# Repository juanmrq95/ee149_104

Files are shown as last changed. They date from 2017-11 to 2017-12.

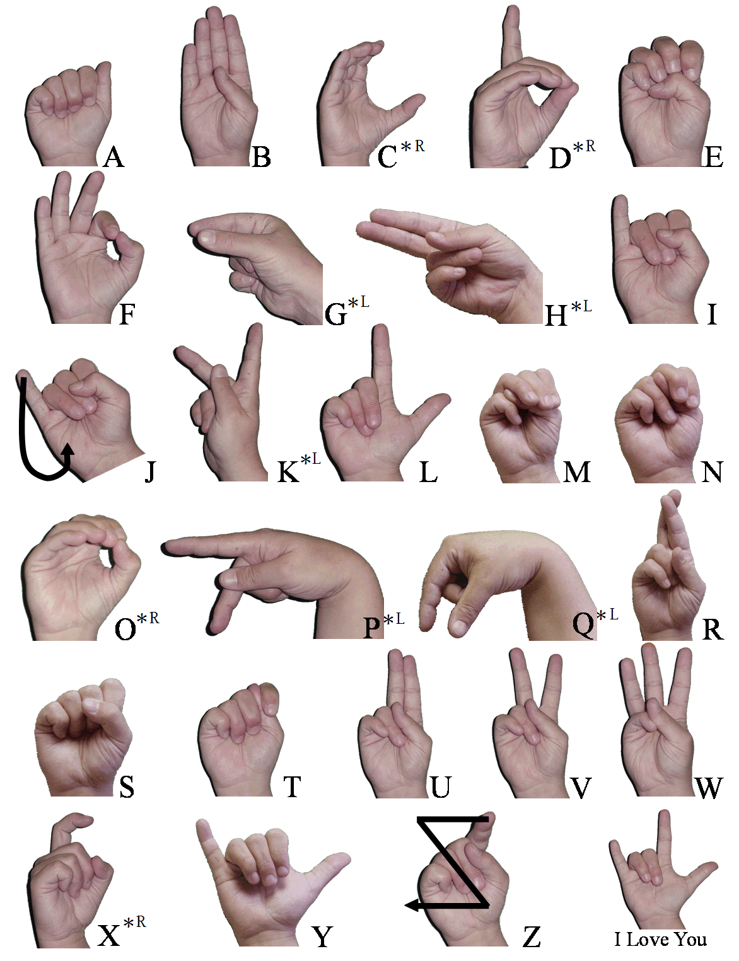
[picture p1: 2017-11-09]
ASLsensing/Pasted image at 2017_10_18 04_46 PM.png

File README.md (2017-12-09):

# ee149_104
EE149 project

ASL Glove:

We created a glove able to interpret every gesture in the ASL alphabet and translate it to text and speech.
We did so by putting touch and flex sensors as well as an IMU embedded on the glove. We designed a sensing circuit 
embedded on the backside of the glove on a flexible PCB sheet as well a small PCB for interfacing with our microprocessor
placed on the wrist.

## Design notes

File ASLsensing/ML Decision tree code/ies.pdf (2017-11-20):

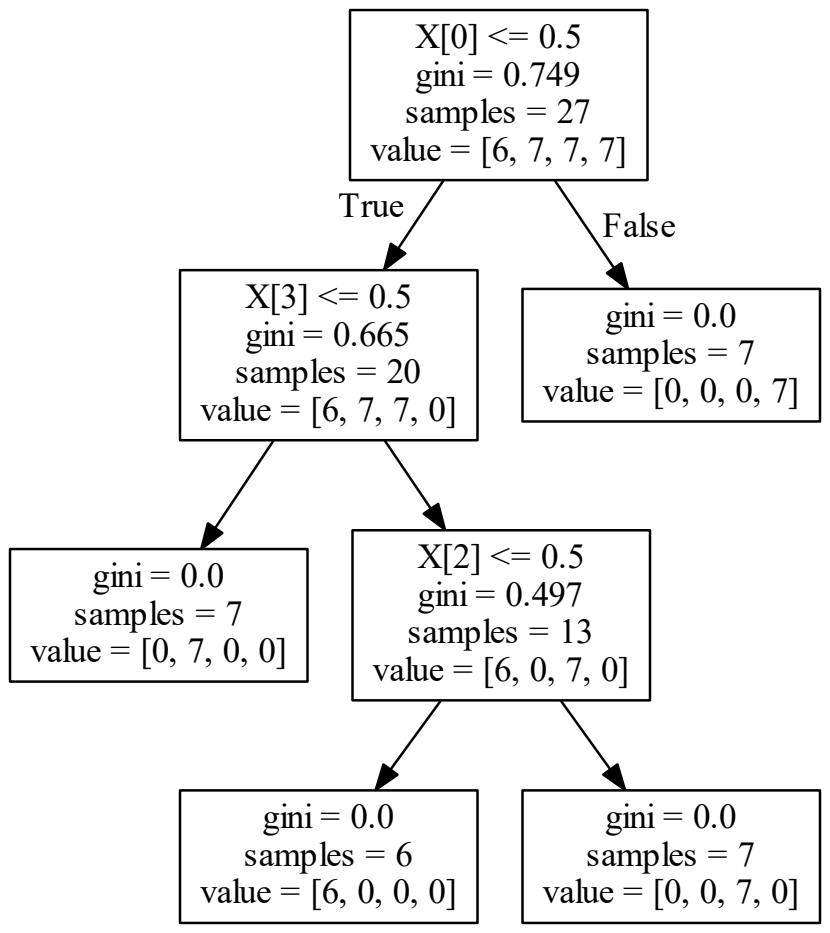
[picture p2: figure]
X[0] <= 0.5 gini = 0.749 samples = 27 value = [6, 7, 7, 7]; X[3] <= 0.5 gini = 0.665 samples = 20 value = [6, 7, 7, 0]; True; gini = 0.0 samples = 7 value = [0, 0, 0, 7]; False; gini = 0.0 samples = 7 value = [0, 7, 0, 0]; X[2] <= 0.5 gini = 0.497 samples = 13 value = [6, 0, 7, 0]; gini = 0.0 samples = 6 value = [6, 0, 0, 0]; gini = 0.0 samples = 7 value = [0, 0, 7, 0]

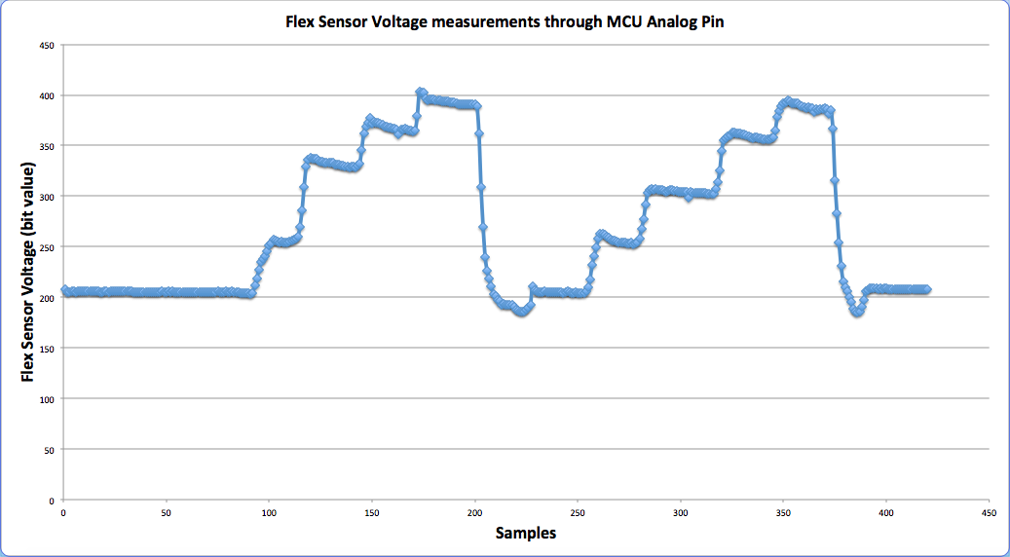
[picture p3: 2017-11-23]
random/flexVoltage.png

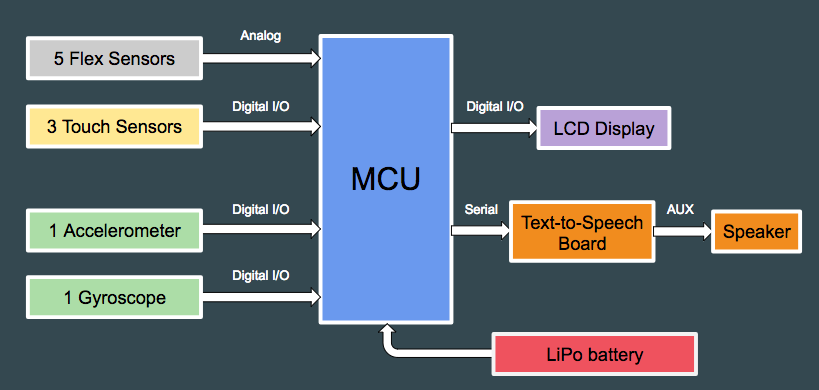
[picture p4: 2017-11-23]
random/Screen Shot 2017-11-21 at 3.47.04 PM.png

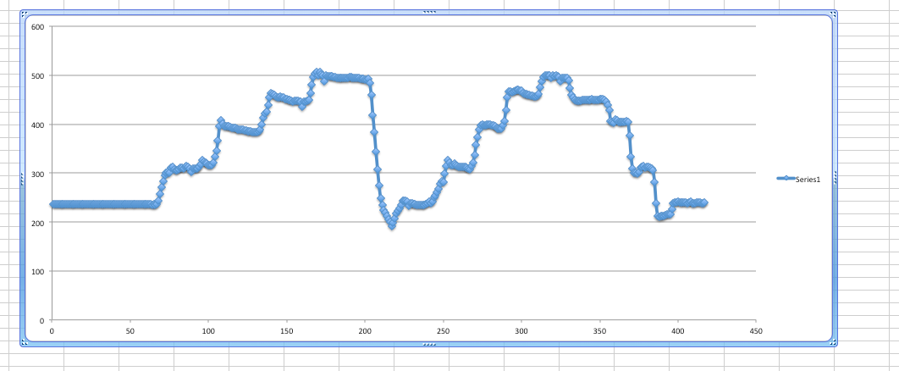
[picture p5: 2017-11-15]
random/Screen Shot 2017-11-13 at 3.06.54 PM.png

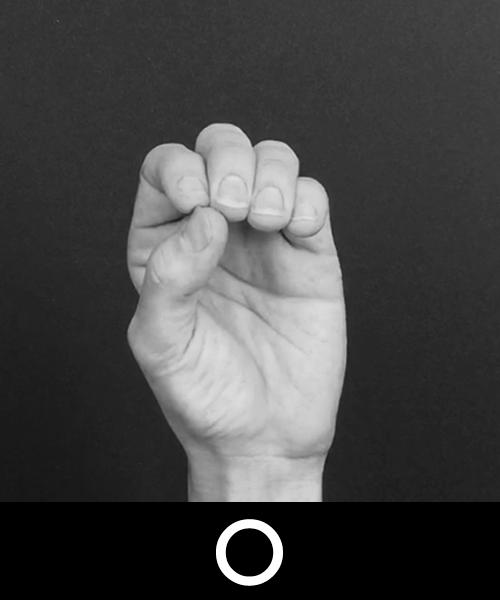
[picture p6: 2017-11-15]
random/O-T.gif

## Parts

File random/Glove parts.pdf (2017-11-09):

Parts to order:

- Silk glove:
https://www.amazon.com/ALASKA-BEAR-Natural-Gloves-Thermal/dp/B00PIMIZWA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 (https://www.amazon.com/ALASKA-BEAR-Natural-Gloves-Thermal/dp/B00PIMIZWA?s=aps)
- Cool glove:
https://www.amazon.com/Terramar-W7467-Body-Sensors-Glove-Liner/dp/B002NPBU36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 (https://www.amazon.com/Terramar-W7467-Body-Sensors-Glove-Liner/dp/B002NPBU36)
- 2 Short flex sensor: https://www.adafruit.com/product/1070
- 3 Long flex sensor: https://www.adafruit.com/product/182
- Microcontroller: FRDM-K64F: https://os.mbed.com/platforms/FRDM-K64F/
- Conductive fabric: https://www.adafruit.com/product/1168

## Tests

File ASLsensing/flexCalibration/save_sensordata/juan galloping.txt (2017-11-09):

500
500
504
508
512
495
495
495
495
495
494
494
493
492
493
494
497
500
504
508
508
501
464
445
438
437
442
451
461
472
483
492
501
508
514
518
521
522
524
525
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

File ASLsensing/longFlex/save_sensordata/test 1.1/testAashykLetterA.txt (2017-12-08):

1r_side 0   m_tip: 0   m_b: 0   m_side: 0   i_tip: 0   i_side: 0   p_side: 0thumb: 6   index: 1   middle: 2   ring: 1   pinky: 2 X: 0.13  Y: 359.35  Z: 0.39
r_side 0   m_tip: 0   m_b: 0   m_side: 0   i_tip: 0   i_side: 0   p_side: 0thumb: 6   index: 1   middle: 2   ring: 1   pinky: 1 X: 0.13  Y: 1.44  Z: 357.90
r_side 0   m_tip: 0   m_b: 0   m_side: 0   i_tip: 0   i_side: 0   p_side: 0thumb: 8   index: 1   middle: 2   ring: 1   pinky: 1 X: 359.97  Y: 3.42  Z: 355.70
r_side 0   m_tip: 0   m_b: 0   m_side: 0   i_tip: 0   i_side: 0   p_side: 0thumb: 6   index: 1   middle: 2   ring: 1   pinky: 1 X: 359.80  Y: 5.33  Z: 353.47
r_side 0   m_tip: 0   m_b: 0   m_side: 0   i_tip: 0   i_side: 0   p_side: 0thumb: 6   index: 0   middle: 2   ring: 1   pinky: 1 X: 359.55  Y: 6.97  Z: 351.30
r_side 0   m_tip: 0   m_b: 0   m_side: 0   i_tip: 0   i_side: 0   p_side: 0thumb: 7   index: 1   middle: 2   ring: 1   pinky: 1 X: 359.28  Y: 8.51  Z: 349.23
r_side 0   m_tip: 0   m_b: 0   m_side: 0   i_tip: 0   i_side: 0   p_side: 0thumb: 8   index: 0   middle: 2   ring: 1   pinky: 1 X: 358.87  Y: 10.12  Z: 347.26
r_side 0   m_tip: 0   m_b: 0   m_side: 0   i_tip: 0   i_side: 0   p_side: 0thumb: 6   index: 1   middle: 2   ring: 1   pinky: 1 X: 358.68  Y: 10.55  Z: 345.72
r_side 0   m_tip: 0   m_b: 0   m_side: 0   i_tip: 0   i_side: 0   p_side: 0thumb: 6   index: 1   middle: 3   ring: 2   pinky: 1 X: 358.55  Y: 11.56  Z: 344.18
r_side 0   m_tip: 0   m_b: 0   m_side: 0   i_tip: 0   i_side: 0   p_side: 0thumb: 6   index: 1   middle: 2   ring: 2   pinky: 1 X: 358.24  Y: 11.93  Z: 342.69
r_side 0   m_tip: 0   m_b: 0   m_side: 0   i_tip: 0   i_side: 0   p_side: 0thumb: 7   index: 1   middle: 2   ring: 1   pinky: 2 X: 356.96  Y: 15.00  Z: 340.89
r_side 0   m_tip: 0   m_b: 0   m_side: 0   i_tip: 0   i_side: 0   p_side: 0thumb: 6   index: 1   middle: 2   ring: 2   pinky: 1 X: 354.32  Y: 22.76  Z: 341.18
r_side 0   m_tip: 0   m_b: 0   m_side: 0   i_tip: 0   i_side: 0   p_side: 0thumb: 6   index: 1   middle: 2   ring: 2   pinky: 1 X: 349.62  Y: 34.87  Z: 338.56
r_side 0   m_tip: 0   m_b: 0   m_side: 0   i_tip: 0   i_side: 0   p_side: 0thumb: 6   index: 2   middle: 3   ring: 3   pinky: 2 X: 332.29  Y: 53.36  Z: 323.33
r_side 0   m_tip: 0   m_b: 0   m_side: 0   i_tip: 0   i_side: 0   p_side: 0thumb: 7   index: 6   middle: 6   ring: 11   pinky: 5 X: 311.81  Y: 60.47  Z: 302.97
r_side 0   m_tip: 0   m_b: 0   m_side: 0   i_tip: 0   i_side: 0   p_side: 0thumb: 10   index: 17   middle: 16   ring: 18   pinky: 15 X: 301.64  Y: 61.44  Z: 292.10
r_side 0   m_tip: 0   m_b: 0   m_side: 0   i_tip: 0   i_side: 0   p_side: 0thumb: 10   index: 21   middle: 20   ring: 21   pinky: 19 X: 292.48  Y: 61.81  Z: 284.01
r_side 0   m_tip: 0   m_b: 0   m_side: 0   i_tip: 0   i_side: 1   p_side: 0thumb: 8   index: 22   middle: 21   ring: 22   pinky: 21 X: 284.69  Y: 67.08  Z: 276.11
r_side 0   m_tip: 0   m_b: 0   m_side: 0   i_tip: 0   i_side: 1   p_side: 0thumb: 8   index: 22   middle: 20   ring: 22   pinky: 21 X: 279.93  Y: 67.51  Z: 271.44
r_side 0   m_tip: 0   m_b: 0   m_side: 0   i_tip: 0   i_side: 1   p_side: 0thumb: 7   index: 21   middle: 20   ring: 21   pinky: 21 X: 278.90  Y: 68.42  Z: 270.73
r_side 0   m_tip: 0   m_b: 0   m_side: 0   i_tip: 0   i_side: 1   p_side: 0thumb: 7   index: 21   middle: 20   ring: 21   pinky: 20 X: 278.82  Y: 67.95  Z: 271.17
r_side 0   m_tip: 0   m_b: 0   m_side: 0   i_tip: 0   i_side: 1   p_side: 0thumb: 7   index: 21   middle: 19   ring: 21   pinky: 20 X: 278.01  Y: 68.12  Z: 270.42
r_side 0   m_tip: 0   m_b: 0   m_side: 0   i_tip: 0   i_side: 1   p_side: 0thumb: 6   index: 21   middle: 19   ring: 21   pinky: 20 X: 276.91  Y: 67.68  Z: 269.46
r_side 0   m_tip: 0   m_b: 0   m_side: 0   i_tip: 0   i_side: 1   p_side: 0thumb: 7   index: 21   middle: 19   ring: 21   pinky: 20 X: 277.85  Y: 66.81  Z: 270.92
r_side 0   m_tip: 0   m_b: 0   m_side: 0   i_tip: 0   i_side: 1   p_side: 0thumb: 7   index: 21   middle: 19   ring: 20   pinky: 20 X: 278.73  Y: 66.07  Z: 271.89
r_side 0   m_tip: 0   m_b: 0   m_side: 0   i_tip: 0   i_side: 1   p_side: 0thumb: 7   index: 21   middle: 19   ring: 20   pinky: 20 X: 278.77  Y: 64.64  Z: 272.66
r_side 0   m_tip: 0   m_b: 0   m_side: 0   i_tip: 0   i_side: 1   p_side: 0thumb: 7   index: 21   middle: 19   ring: 20   pinky: 20 X: 279.12  Y: 64.10  Z: 272.98
r_side 0   m_tip: 0   m_b: 0   m_side: 0   i_tip: 0   i_side: 1   p_side: 0thumb: 7   index: 21   middle: 19   ring: 20   pinky: 20 X: 278.77  Y: 63.57  Z: 272.75
r_side 0   m_tip: 0   m_b: 0   m_side: 0   i_tip: 0   i_side: 1   p_side: 0thumb: 6   index: 20   middle: 19   ring: 20   pinky: 19 X: 277.86  Y: 62.98  Z: 271.75
r_side 0   m_tip: 1   m_b: 0   m_side: 0   i_tip: 0   i_side: 1   p_side: 0thumb: 7   index: 20   middle: 19   ring: 21   pinky: 19 X: 277.18  Y: 62.36  Z: 271.08
r_side 0   m_tip: 1   m_b: 0   m_side: 0   i_tip: 0   i_side: 1   p_side: 0thumb: 7   index: 20   middle: 18   ring: 20   pinky: 19 X: 278.20  Y: 61.51  Z: 271.98
r_side 0   m_tip: 1   m_b: 0   m_side: 0   i_tip: 0   i_side: 1   p_side: 0thumb: 7   index: 20   middle: 19   ring: 20   pinky: 19 X: 277.54  Y: 60.52  Z: 271.65
r_side 0   m_tip: 1   m_b: 0   m_side: 0   i_tip: 0   i_side: 1   p_side: 0thumb: 7   index: 20   middle: 19   ring: 20   pinky: 19 X: 277.64  Y: 59.69  Z: 271.74
r_side 0   m_tip: 1   m_b: 0   m_side: 0   i_tip: 0   i_side: 1   p_side: 0thumb: 6   index: 20   middle: 19   ring: 20   pinky: 19 X: 277.37  Y: 59.08  Z: 271.55
r_side 0   m_tip: 1   m_b: 0   m_side: 0   i_tip: 0   i_side: 1   p_side: 0thumb: 6   index: 20   middle: 18   ring: 19   pinky: 19 X: 279.48  Y: 59.81  Z: 273.34
r_side 0   m_tip: 1   m_b: 0   m_side: 0   i_tip: 0   i_side: 1   p_side: 0thumb: 6   index: 20   middle: 18   ring: 20   pinky: 19 X: 280.43  Y: 59.54  Z: 274.35
r_side 0   m_tip: 1   m_b: 0   m_side: 0   i_tip: 0   i_side: 1   p_side: 0thumb: 7   index: 20   middle: 18   ring: 19   pinky: 19 X: 279.67  Y: 59.21  Z: 273.93
r_side 0   m_tip: 1   m_b: 0   m_side: 0   i_tip: 0   i_side: 1   p_side: 0thumb: 6   index: 20   middle: 18   ring: 19   pinky: 19 X: 280.38  Y: 58.26  Z: 274.65
r_side 0   m_tip: 1   m_b: 0   m_side: 0   i_tip: 0   i_side: 1   p_side: 0thumb: 6   index: 20   middle: 18   ring: 19   pinky: 19 X: 280.50  Y: 57.42  Z: 274.91
r_side 0   m_tip: 1   m_b: 0   m_side: 0   i_tip: 0   i_side: 1   p_side: 0thumb: 6   index: 20   middle: 18   ring: 19   pinky: 19 X: 281.61  Y: 56.66  Z: 275.97

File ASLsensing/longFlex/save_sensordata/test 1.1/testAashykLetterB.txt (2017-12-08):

_r_side 0   m_tip: 0   m_b: 0   m_side: 0   i_tip: 0   i_side: 0   p_side: 0thumb: 4   index: 0   middle: 2   ring: 2   pinky: 2 X: 359.47  Y: 0.78  Z: 359.21
r_side 0   m_tip: 0   m_b: 0   m_side: 0   i_tip: 0   i_side: 0   p_side: 0thumb: 4   index: 0   middle: 2   ring: 2   pinky: 2 X: 359.39  Y: 1.75  Z: 356.61
r_side 0   m_tip: 0   m_b: 0   m_side: 0   i_tip: 0   i_side: 0   p_side: 0thumb: 4   index: 0   middle: 2   ring: 2   pinky: 2 X: 359.32  Y: 2.48  Z: 354.28
r_side 0   m_tip: 0   m_b: 0   m_side: 0   i_tip: 0   i_side: 0   p_side: 0thumb: 4   index: 0   middle: 2   ring: 1   pinky: 2 X: 359.28  Y: 3.41  Z: 351.93
r_side 0   m_tip: 0   m_b: 0   m_side: 0   i_tip: 0   i_side: 0   p_side: 0thumb: 4   index: 0   middle: 2   ring: 2   pinky: 2 X: 359.11  Y: 4.34  Z: 349.74
r_side 0   m_tip: 0   m_b: 0   m_side: 0   i_tip: 0   i_side: 0   p_side: 0thumb: 4   index: 0   middle: 2   ring: 2   pinky: 2 X: 359.00  Y: 5.09  Z: 347.81
r_side 0   m_tip: 0   m_b: 0   m_side: 0   i_tip: 0   i_side: 0   p_side: 0thumb: 4   index: 0   middle: 2   ring: 2   pinky: 2 X: 358.94  Y: 5.48  Z: 346.03
r_side 0   m_tip: 0   m_b: 0   m_side: 0   i_tip: 0   i_side: 0   p_side: 0thumb: 4   index: 0   middle: 2   ring: 2   pinky: 2 X: 359.07  Y: 5.82  Z: 344.29
r_side 0   m_tip: 0   m_b: 0   m_side: 0   i_tip: 0   i_side: 0   p_side: 0thumb: 4   index: 1   middle: 2   ring: 2   pinky: 2 X: 358.94  Y: 5.91  Z: 341.17
r_side 0   m_tip: 0   m_b: 0   m_side: 0   i_tip: 0   i_side: 0   p_side: 0thumb: 4   index: 1   middle: 2   ring: 2   pinky: 2 X: 354.75  Y: 13.08  Z: 339.47
r_side 0   m_tip: 0   m_b: 0   m_side: 0   i_tip: 0   i_side: 0   p_side: 0thumb: 4   index: 1   middle: 2   ring: 3   pinky: 2 X: 347.16  Y: 31.93  Z: 336.28
r_side 0   m_tip: 0   m_b: 0   m_side: 0   i_tip: 0   i_side: 0   p_side: 0thumb: 18   index: 3   middle: 3   ring: 4   pinky: 2 X: 335.03  Y: 46.49  Z: 328.26
r_side 0   m_tip: 0   m_b: 0   m_side: 0   i_tip: 0   i_side: 0   p_side: 0thumb: 20   index: 2   middle: 3   ring: 3   pinky: 2 X: 322.54  Y: 58.75  Z: 322.14
r_side 0   m_tip: 0   m_b: 0   m_side: 0   i_tip: 0   i_side: 0   p_side: 0thumb: 20   index: 1   middle: 3   ring: 2   pinky: 2 X: 314.96  Y: 64.48  Z: 318.64
r_side 0   m_tip: 0   m_b: 0   m_side: 0   i_tip: 0   i_side: 0   p_side: 0thumb: 19   index: 1   middle: 2   ring: 2   pinky: 2 X: 290.35  Y: 68.64  Z: 296.50
r_side 0   m_tip: 0   m_b: 0   m_side: 0   i_tip: 0   i_side: 0   p_side: 0thumb: 19   index: 1   middle: 2   ring: 2   pinky: 2 X: 280.20  Y: 67.24  Z: 288.97
r_side 0   m_tip: 0   m_b: 0   m_side: 0   i_tip: 0   i_side: 0   p_side: 0thumb: 21   index: 2   middle: 2   ring: 2   pinky: 2 X: 278.30  Y: 67.67  Z: 286.71
r_side 0   m_tip: 0   m_b: 0   m_side: 0   i_tip: 0   i_side: 0   p_side: 0thumb: 19   index: 1   middle: 2   ring: 2   pinky: 1 X: 277.95  Y: 66.65  Z: 285.26
r_side 0   m_tip: 0   m_b: 0   m_side: 0   i_tip: 0   i_side: 0   p_side: 0thumb: 19   index: 1   middle: 2   ring: 1   pinky: 1 X: 279.14  Y: 65.26  Z: 284.90
r_side 0   m_tip: 0   m_b: 0   m_side: 0   i_tip: 0   i_side: 0   p_side: 0thumb: 19   index: 1   middle: 2   ring: 1   pinky: 1 X: 281.15  Y: 63.52  Z: 285.59
r_side 0   m_tip: 0   m_b: 0   m_side: 0   i_tip: 0   i_side: 0   p_side: 0thumb: 19   index: 1   middle: 2   ring: 1   pinky: 1 X: 282.74  Y: 62.89  Z: 286.66
r_side 0   m_tip: 0   m_b: 0   m_side: 0   i_tip: 0   i_side: 0   p_side: 0thumb: 18   index: 0   middle: 2   ring: 1   pinky: 1 X: 284.50  Y: 61.96  Z: 287.46
r_side 0   m_tip: 0   m_b: 0   m_side: 0   i_tip: 0   i_side: 0   p_side: 0thumb: 19   index: 1   middle: 2   ring: 1   pinky: 1 X: 287.51  Y: 62.13  Z: 290.24
r_side 0   m_tip: 0   m_b: 0   m_side: 0   i_tip: 0   i_side: 0   p_side: 0thumb: 18   index: 1   middle: 2   ring: 1   pinky: 1 X: 287.23  Y: 62.04  Z: 289.72
r_side 0   m_tip: 0   m_b: 0   m_side: 0   i_tip: 0   i_side: 0   p_side: 0thumb: 18   index: 1   middle: 2   ring: 1   pinky: 1 X: 288.37  Y: 60.62  Z: 291.27
r_side 0   m_tip: 0   m_b: 0   m_side: 0   i_tip: 0   i_side: 0   p_side: 0thumb: 18   index: 1   middle: 2   ring: 1   pinky: 1 X: 290.02  Y: 59.96  Z: 292.60
r_side 0   m_tip: 0   m_b: 0   m_side: 0   i_tip: 0   i_side: 0   p_side: 0thumb: 19   index: 1   middle: 2   ring: 1   pinky: 1 X: 289.76  Y: 59.02  Z: 291.78
r_side 0   m_tip: 0   m_b: 0   m_side: 0   i_tip: 0   i_side: 0   p_side: 0thumb: 18   index: 0   middle: 2   ring: 1   pinky: 1 X: 287.30  Y: 59.18  Z: 289.36
r_side 0   m_tip: 0   m_b: 0   m_side: 0   i_tip: 0   i_side: 0   p_side: 0thumb: 18   index: 0   middle: 2   ring: 1   pinky: 1 X: 286.74  Y: 58.90  Z: 288.61
r_side 0   m_tip: 0   m_b: 0   m_side: 0   i_tip: 0   i_side: 0   p_side: 0thumb: 18   index: 1   middle: 2   ring: 1   pinky: 1 X: 288.34  Y: 57.88  Z: 289.62
r_side 0   m_tip: 0   m_b: 0   m_side: 0   i_tip: 0   i_side: 0   p_side: 0thumb: 18   index: 0   middle: 2   ring: 1   pinky: 1 X: 290.48  Y: 56.76  Z: 291.15
r_side 0   m_tip: 0   m_b: 0   m_side: 0   i_tip: 0   i_side: 0   p_side: 0thumb: 18   index: 1   middle: 2   ring: 1   pinky: 1 X: 291.22  Y: 55.86  Z: 291.68
r_side 0   m_tip: 0   m_b: 0   m_side: 0   i_tip: 0   i_side: 0   p_side: 0thumb: 18   index: 0   middle: 2   ring: 1   pinky: 1 X: 291.06  Y: 55.42  Z: 291.99
r_side 0   m_tip: 0   m_b: 0   m_side: 0   i_tip: 0   i_side: 0   p_side: 0thumb: 19   index: 1   middle: 2   ring: 1   pinky: 1 X: 290.25  Y: 54.37  Z: 291.12
r_side 0   m_tip: 0   m_b: 0   m_side: 0   i_tip: 0   i_side: 0   p_side: 0thumb: 18   index: 1   middle: 2   ring: 1   pinky: 1 X: 290.88  Y: 53.06  Z: 290.71
r_side 0   m_tip: 0   m_b: 0   m_side: 0   i_tip: 0   i_side: 0   p_side: 0thumb: 18   index: 1   middle: 2   ring: 1   pinky: 1 X: 291.80  Y: 51.16  Z: 291.29
r_side 0   m_tip: 0   m_b: 0   m_side: 0   i_tip: 0   i_side: 0   p_side: 0thumb: 18   index: 0   middle: 2   ring: 1   pinky: 1 X: 290.36  Y: 50.74  Z: 289.70
r_side 0   m_tip: 0   m_b: 0   m_side: 0   i_tip: 0   i_side: 0   p_side: 0thumb: 18   index: 1   middle: 2   ring: 1   pinky: 1 X: 289.79  Y: 50.04  Z: 289.32
r_side 0   m_tip: 0   m_b: 0   m_side: 0   i_tip: 0   i_side: 0   p_side: 0thumb: 18   index: 1   middle: 2   ring: 1   pinky: 1 X: 289.44  Y: 49.50  Z: 289.20
r_side 0   m_tip: 0   m_b: 0   m_side: 0   i_tip: 0   i_side: 0   p_side: 0thumb: 18   index: 0   middle: 2   ring: 1   pinky: 1 X: 289.24  Y: 48.61  Z: 289.26

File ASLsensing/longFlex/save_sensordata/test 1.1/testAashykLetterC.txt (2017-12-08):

ðr_side 0   m_tip: 0   m_b: 0   m_side: 0   i_tip: 0   i_side: 0   p_side: 0thumb: 5   index: 0   middle: 2   ring: 1   pinky: 1 X: 359.48  Y: 1.69  Z: 0.39
r_side 0   m_tip: 0   m_b: 0   m_side: 0   i_tip: 0   i_side: 0   p_side: 0thumb: 5   index: 0   middle: 2   ring: 1   pinky: 1 X: 359.42  Y: 2.41  Z: 357.90
r_side 0   m_tip: 0   m_b: 0   m_side: 0   i_tip: 0   i_side: 0   p_side: 0thumb: 5   index: 0   middle: 2   ring: 1   pinky: 1 X: 359.37  Y: 3.25  Z: 355.46
r_side 0   m_tip: 0   m_b: 0   m_side: 0   i_tip: 0   i_side: 0   p_side: 0thumb: 5   index: 0   middle: 2   ring: 1   pinky: 1 X: 359.37  Y: 3.72  Z: 353.05
r_side 0   m_tip: 0   m_b: 0   m_side: 0   i_tip: 0   i_side: 0   p_side: 0thumb: 6   index: 0   middle: 2   ring: 2   pinky: 1 X: 359.29  Y: 4.42  Z: 350.93
r_side 0   m_tip: 0   m_b: 0   m_side: 0   i_tip: 0   i_side: 0   p_side: 0thumb: 6   index: 0   middle: 2   ring: 1   pinky: 1 X: 359.13  Y: 5.17  Z: 348.94
r_side 0   m_tip: 0   m_b: 0   m_side: 0   i_tip: 0   i_side: 0   p_side: 0thumb: 5   index: 0   middle: 2   ring: 1   pinky: 1 X: 358.98  Y: 6.08  Z: 347.13
r_side 0   m_tip: 0   m_b: 0   m_side: 0   i_tip: 0   i_side: 0   p_side: 0thumb: 5   index: 0   middle: 2   ring: 1   pinky: 1 X: 358.81  Y: 6.49  Z: 345.77
r_side 0   m_tip: 0   m_b: 0   m_side: 0   i_tip: 0   i_side: 0   p_side: 0thumb: 4   index: 0   middle: 1   ring: 0   pinky: 2 X: 358.49  Y: 7.22  Z: 344.10
r_side 0   m_tip: 0   m_b: 0   m_side: 0   i_tip: 0   i_side: 0   p_side: 0thumb: 6   index: 0   middle: 2   ring: 1   pinky: 1 X: 358.30  Y: 7.83  Z: 342.69
r_side 0   m_tip: 0   m_b: 0   m_side: 0   i_tip: 0   i_side: 0   p_side: 0thumb: 5   index: 0   middle: 2   ring: 1   pinky: 1 X: 358.03  Y: 8.46  Z: 341.42
r_side 0   m_tip: 0   m_b: 0   m_side: 0   i_tip: 0   i_side: 0   p_side: 0thumb: 5   index: 0   middle: 2   ring: 1   pinky: 1 X: 357.77  Y: 9.36  Z: 340.25
r_side 0   m_tip: 0   m_b: 0   m_side: 0   i_tip: 0   i_side: 0   p_side: 0thumb: 5   index: 0   middle: 1   ring: 1   pinky: 1 X: 357.70  Y: 9.69  Z: 339.22
r_side 0   m_tip: 0   m_b: 0   m_side: 0   i_tip: 0   i_side: 0   p_side: 0thumb: 5   index: 0   middle: 2   ring: 1   pinky: 1 X: 357.48  Y: 10.12  Z: 338.18
r_side 0   m_tip: 0   m_b: 0   m_side: 0   i_tip: 0   i_side: 0   p_side: 0thumb: 5   index: 0   middle: 2   ring: 1   pinky: 1 X: 357.29  Y: 10.28  Z: 337.45
r_side 0   m_tip: 0   m_b: 0   m_side: 0   i_tip: 0   i_side: 0   p_side: 0thumb: 5   index: 0   middle: 2   ring: 1   pinky: 1 X: 357.15  Y: 10.86  Z: 336.66
r_side 0   m_tip: 0   m_b: 0   m_side: 0   i_tip: 0   i_side: 0   p_side: 0thumb: 6   index: 0   middle: 1   ring: 1   pinky: 1 X: 357.17  Y: 10.68  Z: 336.23
r_side 0   m_tip: 0   m_b: 0   m_side: 0   i_tip: 0   i_side: 0   p_side: 0thumb: 5   index: 0   middle: 1   ring: 1   pinky: 1 X: 357.23  Y: 7.20  Z: 334.22
r_side 0   m_tip: 0   m_b: 0   m_side: 0   i_tip: 0   i_side: 0   p_side: 0thumb: 5   index: 0   middle: 2   ring: 1   pinky: 1 X: 354.87  Y: 9.94  Z: 334.68
r_side 0   m_tip: 0   m_b: 0   m_side: 0   i_tip: 0   i_side: 0   p_side: 0thumb: 5   index: 0   middle: 2   ring: 2   pinky: 1 X: 352.17  Y: 16.57  Z: 335.18
r_side 0   m_tip: 0   m_b: 0   m_side: 0   i_tip: 0   i_side: 0   p_side: 0thumb: 5   index: 5   middle: 7   ring: 11   pinky: 2 X: 350.46  Y: 29.31  Z: 335.54
r_side 0   m_tip: 0   m_b: 0   m_side: 0   i_tip: 0   i_side: 0   p_side: 0thumb: 9   index: 15   middle: 15   ring: 17   pinky: 9 X: 346.51  Y: 37.80  Z: 333.40
r_side 0   m_tip: 0   m_b: 0   m_side: 0   i_tip: 0   i_side: 0   p_side: 0thumb: 12   index: 18   middle: 16   ring: 18   pinky: 11 X: 345.68  Y: 41.16  Z: 333.90
r_side 0   m_tip: 0   m_b: 0   m_side: 0   i_tip: 0   i_side: 0   p_side: 0thumb: 13   index: 17   middle: 17   ring: 18   pinky: 12 X: 344.35  Y: 44.59  Z: 334.27
r_side 0   m_tip: 0   m_b: 0   m_side: 0   i_tip: 0   i_side: 0   p_side: 0thumb: 14   index: 17   middle: 16   ring: 18   pinky: 12 X: 343.15  Y: 46.07  Z: 333.75
r_side 0   m_tip: 0   m_b: 0   m_side: 0   i_tip: 0   i_side: 0   p_side: 0thumb: 14   index: 16   middle: 16   ring: 17   pinky: 12 X: 341.54  Y: 46.74  Z: 332.30
r_side 0   m_tip: 0   m_b: 0   m_side: 0   i_tip: 0   i_side: 0   p_side: 0thumb: 13   index: 17   middle: 16   ring: 17   pinky: 11 X: 340.19  Y: 47.38  Z: 331.13
r_side 0   m_tip: 0   m_b: 0   m_side: 0   i_tip: 0   i_side: 0   p_side: 0thumb: 13   index: 16   middle: 16   ring: 17   pinky: 11 X: 338.60  Y: 47.11  Z: 329.30
r_side 0   m_tip: 0   m_b: 0   m_side: 0   i_tip: 0   i_side: 0   p_side: 0thumb: 13   index: 16   middle: 16   ring: 17   pinky: 11 X: 337.13  Y: 46.07  Z: 328.01
r_side 0   m_tip: 0   m_b: 0   m_side: 0   i_tip: 0   i_side: 0   p_side: 0thumb: 13   index: 16   middle: 16   ring: 17   pinky: 11 X: 336.40  Y: 46.31  Z: 327.71
r_side 0   m_tip: 0   m_b: 0   m_side: 0   i_tip: 0   i_side: 0   p_side: 0thumb: 13   index: 17   middle: 16   ring: 16   pinky: 11 X: 334.47  Y: 44.88  Z: 325.49
r_side 0   m_tip: 0   m_b: 0   m_side: 0   i_tip: 0   i_side: 0   p_side: 0thumb: 13   index: 16   middle: 16   ring: 16   pinky: 11 X: 333.81  Y: 44.53  Z: 324.79
r_side 0   m_tip: 0   m_b: 0   m_side: 0   i_tip: 0   i_side: 0   p_side: 0thumb: 13   index: 17   middle: 16   ring: 16   pinky: 11 X: 333.64  Y: 44.84  Z: 324.91
r_side 0   m_tip: 0   m_b: 0   m_side: 0   i_tip: 0   i_side: 0   p_side: 0thumb: 13   index: 16   middle: 16   ring: 16   pinky: 11 X: 333.69  Y: 44.14  Z: 325.15
r_side 0   m_tip: 0   m_b: 0   m_side: 0   i_tip: 0   i_side: 0   p_side: 0thumb: 12   index: 16   middle: 15   ring: 16   pinky: 9 X: 333.30  Y: 43.69  Z: 324.85
r_side 0   m_tip: 0   m_b: 0   m_side: 0   i_tip: 0   i_side: 0   p_side: 0thumb: 13   index: 16   middle: 15   ring: 16   pinky: 10 X: 332.50  Y: 43.50  Z: 324.61
r_side 0   m_tip: 0   m_b: 0   m_side: 0   i_tip: 0   i_side: 0   p_side: 0thumb: 13   index: 15   middle: 16   ring: 17   pinky: 10 X: 332.63  Y: 43.43  Z: 324.93
r_side 0   m_tip: 0   m_b: 0   m_side: 0   i_tip: 0   i_side: 0   p_side: 0thumb: 12   index: 15   middle: 16   ring: 15   pinky: 10 X: 333.31  Y: 42.37  Z: 325.55
r_side 0   m_tip: 0   m_b: 0   m_side: 0   i_tip: 0   i_side: 0   p_side: 0thumb: 12   index: 15   middle: 16   ring: 16   pinky: 10 X: 333.60  Y: 42.37  Z: 326.11
r_side 0   m_tip: 0   m_b: 0   m_side: 0   i_tip: 0   i_side: 0   p_side: 0thumb: 13   index: 16   middle: 15   ring: 16   pinky: 10 X: 333.03  Y: 42.07  Z: 325.81
r_side 0   m_tip: 0   m_b: 0   m_side: 0   i_tip: 0   i_side: 0   p_side: 0thumb: 12   index: 16   middle: 15   ring: 16   pinky: 10 X: 333.32  Y: 41.68  Z: 326.30
r_side 0   m_tip: 0   m_b: 0   m_side: 0   i_tip: 0   i_side: 0   p_side: 0thumb: 12   index: 15   middle: 15   ring: 15   pinky: 10 X: 333.04  Y: 41.06  Z: 326.01
r_side 0   m_tip: 0   m_b: 0   m_side: 0   i_tip: 0   i_side: 0   p_side: 0thumb: 12   index: 16   middle: 15   ring: 15   pinky: 10 X: 332.11  Y: 40.57  Z: 325.58
r_side 0   m_tip: 0   m_b: 0   m_side: 0   i_tip: 0   i_side: 0   p_side: 0thumb: 12   index: 15   middle: 15   ring: 15   pinky: 10 X: 331.71  Y: 40.74  Z: 325.26
r_side 0   m_tip: 0   m_b: 0   m_side: 0   i_tip: 0   i_side: 0   p_side: 0thumb: 12   index: 15   middle: 15   ring: 15   pinky: 10 X: 330.96  Y: 40.36  Z: 324.75
r_side 0   m_tip: 0   m_b: 0   m_side: 0   i_tip: 0   i_side: 0   p_side: 0thumb: 11   index: 16   middle: 15   ring: 15   pinky: 10 X: 331.30  Y: 40.15  Z: 325.09
r_side 0   m_tip: 0   m_b: 0   m_side: 0   i_tip: 0   i_side: 0   p_side: 0thumb: 12   index: 15   middle: 15   ring: 15   pinky: 10 X: 330.54  Y: 40.09  Z: 324.69
r_side 0   m_tip: 0   m_b: 0   m_side: 0   i_tip: 0   i_side: 0   p_side: 0thumb: 12   index: 15   middle: 15   ring: 15   pinky: 10 X: 330.37  Y: 39.12  Z: 324.45
r_side 0   m_tip: 0   m_b: 0   m_side: 0   i_tip: 0   i_side: 0   p_side: 0thumb: 13   index: 16   middle: 15   ring: 15   pinky: 9 X: 330.26  Y: 38.62  Z: 325.25

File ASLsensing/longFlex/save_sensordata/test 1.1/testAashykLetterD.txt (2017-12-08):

ür_side 0   m_tip: 0   m_b: 0   m_side: 0   i_tip: 0   i_side: 0   p_side: 0thumb: 6   index: 1   middle: 2   ring: 2   pinky: 2 X: 358.81  Y: 1.94  Z: 359.32
r_side 0   m_tip: 0   m_b: 0   m_side: 0   i_tip: 0   i_side: 0   p_side: 0thumb: 7   index: 1   middle: 2   ring: 2   pinky: 2 X: 358.74  Y: 3.55  Z: 357.06
r_side 0   m_tip: 0   m_b: 0   m_side: 0   i_tip: 0   i_side: 0   p_side: 0thumb: 6   index: 1   middle: 2   ring: 2   pinky: 2 X: 358.61  Y: 5.17  Z: 354.64
r_side 0   m_tip: 0   m_b: 0   m_side: 0   i_tip: 0   i_side: 0   p_side: 0thumb: 7   index: 1   middle: 2   ring: 2   pinky: 2 X: 358.40  Y: 6.80  Z: 352.57
r_side 0   m_tip: 0   m_b: 0   m_side: 0   i_tip: 0   i_side: 0   p_side: 0thumb: 6   index: 1   middle: 2   ring: 2   pinky: 2 X: 358.17  Y: 8.11  Z: 350.36
r_side 0   m_tip: 0   m_b: 0   m_side: 0   i_tip: 0   i_side: 0   p_side: 0thumb: 7   index: 1   middle: 2   ring: 3   pinky: 1 X: 357.88  Y: 9.39  Z: 348.66
r_side 0   m_tip: 0   m_b: 0   m_side: 0   i_tip: 0   i_side: 0   p_side: 0thumb: 6   index: 1   middle: 2   ring: 2   pinky: 1 X: 357.69  Y: 10.46  Z: 347.10
r_side 0   m_tip: 0   m_b: 0   m_side: 0   i_tip: 0   i_side: 0   p_side: 0thumb: 6   index: 1   middle: 2   ring: 2   pinky: 2 X: 356.56  Y: 12.67  Z: 338.60
r_side 0   m_tip: 0   m_b: 0   m_side: 0   i_tip: 0   i_side: 0   p_side: 0thumb: 7   index: 2   middle: 3   ring: 3   pinky: 1 X: 352.12  Y: 23.47  Z: 338.47
r_side 0   m_tip: 0   m_b: 0   m_side: 0   i_tip: 0   i_side: 0   p_side: 0thumb: 6   index: 2   middle: 11   ring: 13   pinky: 2 X: 341.78  Y: 36.21  Z: 331.49
r_side 0   m_tip: 0   m_b: 0   m_side: 0   i_tip: 0   i_side: 0   p_side: 0thumb: 6   index: 2   middle: 14   ring: 15   pinky: 3 X: 336.55  Y: 40.11  Z: 324.92
r_side 0   m_tip: 0   m_b: 0   m_side: 0   i_tip: 0   i_side: 0   p_side: 0thumb: 7   index: 1   middle: 15   ring: 17   pinky: 6 X: 327.63  Y: 43.92  Z: 316.87
r_side 0   m_tip: 0   m_b: 0   m_side: 0   i_tip: 0   i_side: 0   p_side: 0thumb: 9   index: 1   middle: 16   ring: 17   pinky: 9 X: 322.69  Y: 45.01  Z: 311.96
r_side 0   m_tip: 0   m_b: 0   m_side: 0   i_tip: 0   i_side: 0   p_side: 0thumb: 12   index: 1   middle: 15   ring: 17   pinky: 9 X: 321.60  Y: 44.64  Z: 310.20
r_side 0   m_tip: 1   m_b: 0   m_side: 0   i_tip: 0   i_side: 0   p_side: 0thumb: 12   index: 1   middle: 14   ring: 17   pinky: 8 X: 321.65  Y: 44.09  Z: 309.62
r_side 0   m_tip: 1   m_b: 0   m_side: 0   i_tip: 0   i_side: 0   p_side: 0thumb: 12   index: 1   middle: 15   ring: 18   pinky: 8 X: 322.46  Y: 43.40  Z: 308.68
r_side 0   m_tip: 1   m_b: 0   m_side: 0   i_tip: 0   i_side: 0   p_side: 0thumb: 11   index: 1   middle: 16   ring: 18   pinky: 9 X: 323.11  Y: 43.14  Z: 308.49
r_side 0   m_tip: 1   m_b: 0   m_side: 0   i_tip: 0   i_side: 0   p_side: 0thumb: 11   index: 2   middle: 15   ring: 17   pinky: 9 X: 323.01  Y: 40.29  Z: 307.97
r_side 0   m_tip: 1   m_b: 0   m_side: 0   i_tip: 0   i_side: 0   p_side: 0thumb: 11   index: 1   middle: 15   ring: 17   pinky: 10 X: 321.75  Y: 39.57  Z: 307.04
r_side 0   m_tip: 1   m_b: 0   m_side: 0   i_tip: 0   i_side: 0   p_side: 0thumb: 11   index: 1   middle: 14   ring: 17   pinky: 10 X: 320.71  Y: 39.69  Z: 306.17
r_side 0   m_tip: 1   m_b: 0   m_side: 0   i_tip: 0   i_side: 0   p_side: 0thumb: 11   index: 1   middle: 15   ring: 17   pinky: 10 X: 321.41  Y: 39.38  Z: 306.32
r_side 0   m_tip: 1   m_b: 0   m_side: 0   i_tip: 0   i_side: 0   p_side: 0thumb: 11   index: 1   middle: 14   ring: 17   pinky: 10 X: 321.06  Y: 39.03  Z: 305.29
r_side 0   m_tip: 1   m_b: 0   m_side: 0   i_tip: 0   i_side: 0   p_side: 0thumb: 11   index: 1   middle: 14   ring: 17   pinky: 9 X: 320.53  Y: 39.51  Z: 304.29
r_side 0   m_tip: 1   m_b: 0   m_side: 0   i_tip: 0   i_side: 0   p_side: 0thumb: 11   index: 0   middle: 14   ring: 17   pinky: 9 X: 320.58  Y: 40.26  Z: 303.53
r_side 0   m_tip: 1   m_b: 0   m_side: 0   i_tip: 0   i_side: 0   p_side: 0thumb: 12   index: 1   middle: 14   ring: 17   pinky: 9 X: 319.44  Y: 41.17  Z: 302.79
r_side 0   m_tip: 1   m_b: 0   m_side: 0   i_tip: 0   i_side: 0   p_side: 0thumb: 11   index: 1   middle: 14   ring: 16   pinky: 9 X: 317.33  Y: 43.11  Z: 301.54
r_side 0   m_tip: 1   m_b: 0   m_side: 0   i_tip: 0   i_side: 0   p_side: 0thumb: 11   index: 1   middle: 14   ring: 16   pinky: 9 X: 317.07  Y: 43.85  Z: 301.10
r_side 0   m_tip: 1   m_b: 0   m_side: 0   i_tip: 0   i_side: 0   p_side: 0thumb: 11   index: 0   middle: 14   ring: 16   pinky: 9 X: 316.26  Y: 43.93  Z: 300.39
r_side 0   m_tip: 1   m_b: 0   m_side: 0   i_tip: 0   i_side: 0   p_side: 0thumb: 11   index: 0   middle: 14   ring: 16   pinky: 9 X: 315.65  Y: 44.30  Z: 299.54
r_side 0   m_tip: 1   m_b: 0   m_side: 0   i_tip: 0   i_side: 0   p_side: 0thumb: 11   index: 0   middle: 14   ring: 16   pinky: 9 X: 315.70  Y: 44.57  Z: 299.57
r_side 0   m_tip: 1   m_b: 0   m_side: 0   i_tip: 0   i_side: 0   p_side: 0thumb: 11   index: 1   middle: 14   ring: 16   pinky: 9 X: 316.35  Y: 44.34  Z: 300.63
r_side 0   m_tip: 1   m_b: 0   m_side: 0   i_tip: 0   i_side: 0   p_side: 0thumb: 11   index: 1   middle: 14   ring: 16   pinky: 9 X: 317.33  Y: 43.72  Z: 301.03
r_side 0   m_tip: 1   m_b: 0   m_side: 0   i_tip: 0   i_side: 0   p_side: 0thumb: 11   index: 1   middle: 14   ring: 16   pinky: 9 X: 315.74  Y: 44.04  Z: 299.64
r_side 0   m_tip: 1   m_b: 0   m_side: 0   i_tip: 0   i_side: 0   p_side: 0thumb: 11   index: 0   middle: 14   ring: 16   pinky: 9 X: 316.22  Y: 43.02  Z: 299.60
r_side 0   m_tip: 1   m_b: 0   m_side: 0   i_tip: 0   i_side: 0   p_side: 0thumb: 11   index: 1   middle: 14   ring: 16   pinky: 10 X: 315.02  Y: 43.20  Z: 299.25
r_side 0   m_tip: 1   m_b: 0   m_side: 0   i_tip: 0   i_side: 0   p_side: 0thumb: 11   index: 0   middle: 14   ring: 16   pinky: 9 X: 315.92  Y: 43.08  Z: 300.32
r_side 0   m_tip: 1   m_b: 0   m_side: 0   i_tip: 0   i_side: 0   p_side: 0thumb: 11   index: 0   middle: 14   ring: 16   pinky: 9 X: 317.48  Y: 42.72  Z: 302.11
r_side 0   m_tip: 1   m_b: 0   m_side: 0   i_tip: 0   i_side: 0   p_side: 0thumb: 12   index: 1   middle: 14   ring: 16   pinky: 10 X: 317.65  Y: 42.23  Z: 302.23
r_side 0   m_tip: 1   m_b: 0   m_side: 0   i_tip: 0   i_side: 0   p_side: 0thumb: 11   index: 1   middle: 13   ring: 15   pinky: 9 X: 318.49  Y: 41.56  Z: 303.00
r_side 0   m_tip: 1   m_b: 0   m_side: 0   i_tip: 0   i_side: 0   p_side: 0thumb: 11   index: 0   middle: 14   ring: 16   pinky: 10 X: 318.27  Y: 41.21  Z: 302.60
r_side 0   m_tip: 1   m_b: 0   m_side: 0   i_tip: 0   i_side: 0   p_side: 0thumb: 11   index: 0   middle: 14   ring: 15   pinky: 9 X: 318.68  Y: 40.66  Z: 303.03
r_side 0   m_tip: 1   m_b: 0   m_side: 0   i_tip: 0   i_side: 0   p_side: 0thumb: 11   index: 1   middle: 14   ring: 15   pinky: 9 X: 318.91  Y: 40.29  Z: 303.43
r_side 0   m_tip: 1   m_b: 0   m_side: 0   i_tip: 0   i_side: 0   p_side: 0thumb: 11   index: 0   middle: 14   ring: 15   pinky: 9 X: 318.97  Y: 39.47  Z: 303.17
r_side 0   m_tip: 1   m_b: 0   m_side: 0   i_tip: 0   i_side: 0   p_side: 0thumb: 11   index: 0   middle: 13   ring: 15   pinky: 9 X: 318.55  Y: 39.37  Z: 302.63
r_side 0   m_tip: 1   m_b: 0   m_side: 0   i_tip: 0   i_side: 0   p_side: 0thumb: 11   index: 0   middle: 13   ring: 15   pinky: 9 X: 318.28  Y: 38.94  Z: 302.70
r_side 0   m_tip: 1   m_b: 0   m_side: 0   i_tip: 0   i_side: 0   p_side: 0thumb: 11   index: 0   middle: 13   ring: 15   pinky: 9 X: 318.82  Y: 38.17  Z: 303.19

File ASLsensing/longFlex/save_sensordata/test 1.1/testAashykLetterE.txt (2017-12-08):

ír_side 0   m_tip: 0   m_b: 0   m_side: 0   i_tip: 0   i_side: 0   p_side: 0thumb: 6   index: 0   middle: 2   ring: 2   pinky: 2 X: 360.00  Y: 0.52  Z: 358.95
r_side 0   m_tip: 0   m_b: 0   m_side: 0   i_tip: 0   i_side: 0   p_side: 0thumb: 8   index: 0   middle: 2   ring: 2   pinky: 2 X: 359.92  Y: 1.89  Z: 356.72
r_side 0   m_tip: 0   m_b: 0   m_side: 0   i_tip: 0   i_side: 0   p_side: 0thumb: 5   index: 0   middle: 2   ring: 2   pinky: 1 X: 359.74  Y: 3.35  Z: 354.86
r_side 0   m_tip: 0   m_b: 0   m_side: 0   i_tip: 0   i_side: 0   p_side: 0thumb: 6   index: 0   middle: 2   ring: 2   pinky: 2 X: 359.62  Y: 4.57  Z: 352.80
r_side 0   m_tip: 0   m_b: 0   m_side: 0   i_tip: 0   i_side: 0   p_side: 0thumb: 6   index: 0   middle: 2   ring: 2   pinky: 2 X: 359.48  Y: 5.79  Z: 351.27
r_side 0   m_tip: 0   m_b: 0   m_side: 0   i_tip: 0   i_side: 0   p_side: 0thumb: 5   index: 1   middle: 2   ring: 2   pinky: 2 X: 359.28  Y: 6.61  Z: 349.65
r_side 0   m_tip: 0   m_b: 0   m_side: 0   i_tip: 0   i_side: 0   p_side: 0thumb: 6   index: 0   middle: 2   ring: 2   pinky: 2 X: 359.10  Y: 7.45  Z: 348.04
r_side 0   m_tip: 0   m_b: 0   m_side: 0   i_tip: 0   i_side: 0   p_side: 0thumb: 5   index: 0   middle: 2   ring: 2   pinky: 1 X: 358.92  Y: 8.35  Z: 346.66
r_side 0   m_tip: 0   m_b: 0   m_side: 0   i_tip: 0   i_side: 0   p_side: 0thumb: 6   index: 0   middle: 2   ring: 2   pinky: 2 X: 358.63  Y: 9.57  Z: 345.36
r_side 0   m_tip: 0   m_b: 0   m_side: 0   i_tip: 0   i_side: 0   p_side: 0thumb: 6   index: 0   middle: 2   ring: 2   pinky: 2 X: 358.42  Y: 9.85  Z: 344.22
r_side 0   m_tip: 0   m_b: 0   m_side: 0   i_tip: 0   i_side: 0   p_side: 0thumb: 6   index: 0   middle: 2   ring: 2   pinky: 2 X: 358.15  Y: 10.49  Z: 343.10
r_side 0   m_tip: 0   m_b: 0   m_side: 0   i_tip: 0   i_side: 0   p_side: 0thumb: 6   index: 0   middle: 2   ring: 2   pinky: 2 X: 357.91  Y: 11.16  Z: 342.18
r_side 0   m_tip: 0   m_b: 0   m_side: 0   i_tip: 0   i_side: 0   p_side: 0thumb: 5   index: 0   middle: 3   ring: 2   pinky: 2 X: 357.68  Y: 11.88  Z: 341.28
r_side 0   m_tip: 0   m_b: 0   m_side: 0   i_tip: 0   i_side: 0   p_side: 0thumb: 6   index: -1   middle: 2   ring: 2   pinky: 2 X: 357.50  Y: 12.50  Z: 340.45
r_side 0   m_tip: 0   m_b: 0   m_side: 0   i_tip: 0   i_side: 0   p_side: 0thumb: 6   index: 0   middle: 2   ring: 2   pinky: 2 X: 357.40  Y: 12.43  Z: 339.58
r_side 0   m_tip: 0   m_b: 0   m_side: 0   i_tip: 0   i_side: 0   p_side: 0thumb: 6   index: 0   middle: 2   ring: 0   pinky: 2 X: 357.63  Y: 10.67  Z: 338.29
r_side 0   m_tip: 0   m_b: 0   m_side: 0   i_tip: 0   i_side: 0   p_side: 0thumb: 6   index: 0   middle: 2   ring: 2   pinky: 1 X: 356.56  Y: 14.40  Z: 335.07
r_side 0   m_tip: 0   m_b: 0   m_side: 0   i_tip: 0   i_side: 0   p_side: 0thumb: 6   index: 0   middle: 2   ring: 2   pinky: 1 X: 354.69  Y: 19.65  Z: 336.07
r_side 0   m_tip: 0   m_b: 0   m_side: 0   i_tip: 0   i_side: 0   p_side: 0thumb: 6   index: 0   middle: 2   ring: 2   pinky: 2 X: 351.11  Y: 30.15  Z: 336.02
r_side 0   m_tip: 0   m_b: 0   m_side: 0   i_tip: 0   i_side: 0   p_side: 0thumb: 6   index: 1   middle: 3   ring: 2   pinky: 2 X: 345.71  Y: 42.80  Z: 333.54
r_side 0   m_tip: 0   m_b: 0   m_side: 0   i_tip: 0   i_side: 0   p_side: 0thumb: 5   index: 13   middle: 14   ring: 16   pinky: 5 X: 339.01  Y: 56.00  Z: 330.14
r_side 0   m_tip: 0   m_b: 0   m_side: 0   i_tip: 0   i_side: 0   p_side: 0thumb: 8   index: 19   middle: 18   ring: 20   pinky: 14 X: 333.65  Y: 61.61  Z: 324.30
r_side 0   m_tip: 0   m_b: 0   m_side: 0   i_tip: 0   i_side: 0   p_side: 0thumb: 22   index: 21   middle: 19   ring: 21   pinky: 17 X: 330.38  Y: 62.88  Z: 319.96
r_side 0   m_tip: 0   m_b: 0   m_side: 0   i_tip: 0   i_side: 0   p_side: 0thumb: 23   index: 22   middle: 20   ring: 21   pinky: 19 X: 324.27  Y: 65.05  Z: 314.98
r_side 0   m_tip: 0   m_b: 0   m_side: 0   i_tip: 0   i_side: 0   p_side: 0thumb: 23   index: 22   middle: 20   ring: 22   pinky: 19 X: 323.20  Y: 65.58  Z: 314.40
r_side 0   m_tip: 0   m_b: 0   m_side: 0   i_tip: 0   i_side: 0   p_side: 0thumb: 23   index: 22   middle: 20   ring: 22   pinky: 20 X: 324.69  Y: 64.05  Z: 314.79
r_side 0   m_tip: 0   m_b: 0   m_side: 0   i_tip: 0   i_side: 0   p_side: 0thumb: 23   index: 22   middle: 20   ring: 22   pinky: 20 X: 319.04  Y: 65.70  Z: 308.31
r_side 0   m_tip: 0   m_b: 0   m_side: 0   i_tip: 0   i_side: 0   p_side: 0thumb: 23   index: 22   middle: 20   ring: 22   pinky: 20 X: 326.85  Y: 64.97  Z: 313.77
r_side 0   m_tip: 0   m_b: 0   m_side: 0   i_tip: 0   i_side: 0   p_side: 0thumb: 22   index: 21   middle: 20   ring: 22   pinky: 20 X: 326.58  Y: 63.60  Z: 313.29
r_side 0   m_tip: 0   m_b: 0   m_side: 0   i_tip: 0   i_side: 0   p_side: 0thumb: 22   index: 22   middle: 20   ring: 21   pinky: 19 X: 327.50  Y: 61.99  Z: 314.07
r_side 0   m_tip: 0   m_b: 0   m_side: 0   i_tip: 0   i_side: 0   p_side: 0thumb: 22   index: 21   middle: 19   ring: 21   pinky: 19 X: 325.81  Y: 62.98  Z: 313.19
r_side 0   m_tip: 0   m_b: 0   m_side: 0   i_tip: 0   i_side: 0   p_side: 0thumb: 22   index: 21   middle: 19   ring: 21   pinky: 19 X: 322.91  Y: 62.75  Z: 311.06
r_side 0   m_tip: 0   m_b: 0   m_side: 0   i_tip: 0   i_side: 0   p_side: 0thumb: 23   index: 21   middle: 19   ring: 20   pinky: 19 X: 323.18  Y: 61.49  Z: 311.73
r_side 0   m_tip: 0   m_b: 0   m_side: 0   i_tip: 0   i_side: 0   p_side: 0thumb: 22   index: 20   middle: 19   ring: 21   pinky: 19 X: 322.13  Y: 62.50  Z: 310.91
r_side 0   m_tip: 0   m_b: 0   m_side: 0   i_tip: 0   i_side: 0   p_side: 0thumb: 22   index: 21   middle: 19   ring: 20   pinky: 19 X: 322.32  Y: 61.37  Z: 311.30
r_side 0   m_tip: 0   m_b: 0   m_side: 0   i_tip: 0   i_side: 0   p_side: 0thumb: 21   index: 21   middle: 19   ring: 20   pinky: 19 X: 320.49  Y: 62.36  Z: 309.94
r_side 0   m_tip: 0   m_b: 0   m_side: 0   i_tip: 0   i_side: 0   p_side: 0thumb: 21   index: 21   middle: 19   ring: 20   pinky: 19 X: 320.88  Y: 62.04  Z: 310.12
r_side 0   m_tip: 0   m_b: 0   m_side: 0   i_tip: 0   i_side: 0   p_side: 0thumb: 21   index: 21   middle: 19   ring: 20   pinky: 19 X: 321.80  Y: 61.02  Z: 311.10
r_side 0   m_tip: 0   m_b: 0   m_side: 0   i_tip: 0   i_side: 0   p_side: 0thumb: 21   index: 20   middle: 19   ring: 20   pinky: 19 X: 320.04  Y: 60.67  Z: 309.05
r_side 0   m_tip: 0   m_b: 0   m_side: 0   i_tip: 0   i_side: 0   p_side: 0thumb: 21   index: 21   middle: 19   ring: 20   pinky: 19 X: 320.58  Y: 59.84  Z: 309.83
r_side 0   m_tip: 0   m_b: 0   m_side: 0   i_tip: 0   i_side: 0   p_side: 0thumb: 21   index: 20   middle: 19   ring: 20   pinky: 19 X: 319.12  Y: 59.46  Z: 308.72
r_side 0   m_tip: 0   m_b: 0   m_side: 0   i_tip: 0   i_side: 0   p_side: 0thumb: 21   index: 20   middle: 19   ring: 20   pinky: 18 X: 317.09  Y: 59.11  Z: 306.63
r_side 0   m_tip: 0   m_b: 0   m_side: 0   i_tip: 0   i_side: 0   p_side: 0thumb: 21   index: 20   middle: 18   ring: 20   pinky: 18 X: 317.33  Y: 59.35  Z: 307.27
r_side 0   m_tip: 0   m_b: 0   m_side: 0   i_tip: 0   i_side: 0   p_side: 0thumb: 21   index: 21   middle: 18   ring: 20   pinky: 18 X: 315.22  Y: 60.38  Z: 305.11
r_side 0   m_tip: 0   m_b: 0   m_side: 0   i_tip: 0   i_side: 0   p_side: 0thumb: 22   index: 20   middle: 18   ring: 20   pinky: 18 X: 315.83  Y: 59.17  Z: 306.27
r_side 0   m_tip: 0   m_b: 0   m_side: 0   i_tip: 0   i_side: 0   p_side: 0thumb: 21   index: 20   middle: 18   ring: 20   pinky: 18 X: 317.14  Y: 57.82  Z: 308.07
r_side 0   m_tip: 0   m_b: 0   m_side: 0   i_tip: 0   i_side: 0   p_side: 0thumb: 21   index: 20   middle: 18   ring: 20   pinky: 18 X: 316.16  Y: 57.76  Z: 307.21
r_side 0   m_tip: 0   m_b: 0   m_side: 0   i_tip: 0   i_side: 0   p_side: 0thumb: 21   index: 20   middle: 18   ring: 20   pinky: 18 X: 317.62  Y: 56.53  Z: 308.57
r_side 0   m_tip: 0   m_b: 0   m_side: 0   i_tip: 0   i_side: 0   p_side: 0thumb: 21   index: 20   middle: 18   ring: 20   pinky: 18 X: 316.72  Y: 56.42  Z: 307.63
r_side 0   m_tip: 0   m_b: 0   m_side: 0   i_tip: 0   i_side: 0   p_side: 0thumb: 20   index: 20   middle: 18   ring: 20   pinky: 18 X: 316.63  Y: 55.93  Z: 307.92
r_side 0   m_tip: 0   m_b: 0   m_side: 0   i_tip: 0   i_side: 0   p_side: 0thumb: 21   index: 20   middle: 18   ring: 20   pinky: 18 X: 318.19  Y: 53.99  Z: 308.75
r_side 0   m_tip: 0   m_b: 0   m_side: 0   i_tip: 0   i_side: 0   p_side: 0thumb: 21   index: 20   middle: 18   ring: 20   pinky: 18 X: 316.93  Y: 53.92  Z: 307.54
r_side 0   m_tip: 0   m_b: 0   m_side: 0   i_tip: 0   i_side: 0   p_side: 0thumb: 21   index: 20   middle: 18   ring: 19   pinky: 18 X: 317.22  Y: 53.33  Z: 308.36
r_side 0   m_tip: 0   m_b: 0   m_side: 0   i_tip: 0   i_side: 0   p_side: 0thumb: 20   index: 20   middle: 18   ring: 19   pinky: 18 X: 317.29  Y: 52.77  Z: 309.20
r_side 0   m_tip: 0   m_b: 0   m_side: 0   i_tip: 0   i_side: 0   p_side: 0thumb: 21   index: 20   middle: 18   ring: 19   pinky: 18 X: 316.52  Y: 53.50  Z: 309.37
r_side 0   m_tip: 0   m_b: 0   m_side: 0   i_tip: 0   i_side: 0   p_side: 0thumb: 20   index: 19   middle: 18   ring: 20   pinky: 18 X: 313.35  Y: 54.14  Z: 307.64
r_side 0   m_tip: 0   m_b: 0   m_side: 0   i_tip: 0   i_side: 0   p_side: 0thumb: 21   index: 20   middle: 18   ring: 19   pinky: 18 X: 314.95  Y: 52.65  Z: 309.61
r_side 0   m_tip: 0   m_b: 0   m_side: 0   i_tip: 0   i_side: 0   p_side: 0thumb: 20   index: 20   middle: 18   ring: 19   pinky: 18 X: 314.35  Y: 52.42  Z: 309.45
r_side 0   m_tip: 0   m_b: 0   m_side: 0   i_tip: 0   i_side: 0   p_side: 0thumb: 20   index: 20   middle: 18   ring: 19   pinky: 18 X: 314.01  Y: 51.35  Z: 309.16
r_side 0   m_tip: 0   m_b: 0   m_side: 0   i_tip: 0   i_side: 0   p_side: 0thumb: 20   index: 20   middle: 18   ring: 19   pinky: 18 X: 313.51  Y: 51.92  Z: 309.01
r_side 0   m_tip: 0   m_b: 0   m_side: 0   i_tip: 0   i_side: 0   p_side: 0thumb: 20   index: 20   middle: 18   ring: 19   pinky: 18 X: 311.83  Y: 51.82  Z: 307.10
r_side 0   m_tip: 0   m_b: 0   m_side: 0   i_tip: 0   i_side: 0   p_side: 0thumb: 20   index: 20   middle: 18   ring: 19   pinky: 18 X: 312.59  Y: 51.17  Z: 308.39
r_side 0   m_tip: 0   m_b: 0   m_side: 0   i_tip: 0   i_side: 0   p_side: 0thumb: 20   index: 20   middle: 18   ring: 19   pinky: 18 X: 311.77  Y: 51.08  Z: 307.52
r_side 0   m_tip: 0   m_b: 0   m_side: 0   i_tip: 0   i_side: 0   p_side: 0thumb: 20   index: 19   middle: 18   ring: 19   pinky: 18 X: 310.74  Y: 50.90  Z: 306.72
r_side 0   m_tip: 0   m_b: 0   m_side: 0   i_tip: 0   i_side: 0   p_side: 0thumb: 20   index: 19   middle: 18   ring: 19   pinky: 18 X: 311.56  Y: 49.78  Z: 307.15
r_side 0   m_tip: 0   m_b: 0   m_side: 0   i_tip: 0   i_side: 0   p_side: 0thumb: 20   index: 20   middle: 18   ring: 19   pinky: 18 X: 311.60  Y: 48.22  Z: 307.23
r_side 0   m_tip: 0   m_b: 0   m_side: 0   i_tip: 0   i_side: 0   p_side: 0thumb: 20   index: 20   middle: 18   ring: 19   pinky: 17 X: 311.29  Y: 47.38  Z: 307.04
r_side 0   m_tip: 0   m_b: 0   m_side: 0   i_tip: 0   i_side: 0   p_side: 0thumb: 21   index: 20   middle: 18   ring: 19   pinky: 18 X: 311.83  Y: 46.96  Z: 307.62
r_side 0   m_tip: 0   m_b: 0   m_side: 0   i_tip: 0   i_side: 0   p_side: 0thumb: 20   index: 20   middle: 18   ring: 19   pinky: 18 X: 310.62  Y: 46.33  Z: 306.43
r_side 0   m_tip: 0   m_b: 0   m_side: 0   i_tip: 0   i_side: 0   p_side: 0thumb: 20   index: 20   middle: 18   ring: 19   pinky: 18 X: 310.28  Y: 45.81  Z: 306.31
r_side 0   m_tip: 0   m_b: 0   m_side: 0   i_tip: 0   i_side: 0   p_side: 0thumb: 20   index: 20   middle: 18   ring: 19   pinky: 18 X: 309.83  Y: 44.64  Z: 305.57
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

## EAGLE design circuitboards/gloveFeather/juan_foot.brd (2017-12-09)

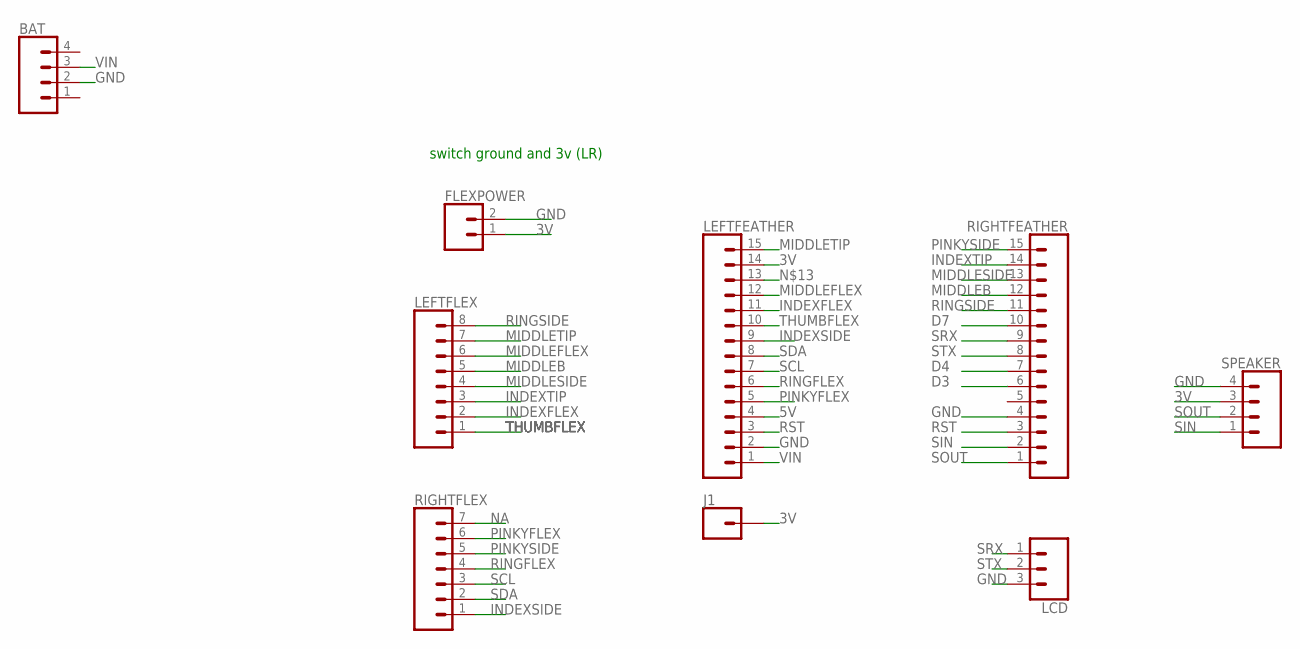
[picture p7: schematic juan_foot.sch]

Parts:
BAT: CONN_04; 1X04
FLEXPOWER: CONN_02; 1X02
J1: CONN_01; 1X01
LCD: CONN_03; 1X03
LEFTFEATHER: CONN_15; 1X15
LEFTFLEX: CONN_08"; 1X08
RIGHTFEATHER: CONN_15; 1X15
RIGHTFLEX: CONN_07; 1X07
SPEAKER: CONN_04; 1X04

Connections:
3V: FLEXPOWER.1, J1.1, LEFTFEATHER.14, SPEAKER.3
5V: LEFTFEATHER.4
D3: RIGHTFEATHER.6
D4: RIGHTFEATHER.7
D7: RIGHTFEATHER.10
GND: BAT.2, FLEXPOWER.2, LCD.3, LEFTFEATHER.2, RIGHTFEATHER.4, SPEAKER.4
INDEXFLEX: LEFTFEATHER.11, LEFTFLEX.2
INDEXSIDE: LEFTFEATHER.9, RIGHTFLEX.1
INDEXTIP: LEFTFLEX.3, RIGHTFEATHER.14
MIDDLEB: LEFTFLEX.5, RIGHTFEATHER.12
MIDDLEFLEX: LEFTFEATHER.12, LEFTFLEX.6
MIDDLESIDE: LEFTFLEX.4, RIGHTFEATHER.13
MIDDLETIP: LEFTFEATHER.15, LEFTFLEX.7
NA: RIGHTFLEX.7
PINKYFLEX: LEFTFEATHER.5, RIGHTFLEX.6
PINKYSIDE: RIGHTFEATHER.15, RIGHTFLEX.5
RINGFLEX: LEFTFEATHER.6, RIGHTFLEX.4
RINGSIDE: LEFTFLEX.8, RIGHTFEATHER.11
RST: LEFTFEATHER.3, RIGHTFEATHER.3
SCL: LEFTFEATHER.7, RIGHTFLEX.3
SDA: LEFTFEATHER.8, RIGHTFLEX.2
SIN: RIGHTFEATHER.2, SPEAKER.1
SOUT: RIGHTFEATHER.1, SPEAKER.2
SRX: LCD.1, RIGHTFEATHER.9
STX: LCD.2, RIGHTFEATHER.8
THUMBFLEX: LEFTFEATHER.10, LEFTFLEX.1
VIN: BAT.3, LEFTFEATHER.1

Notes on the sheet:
switch ground and 3v (LR)

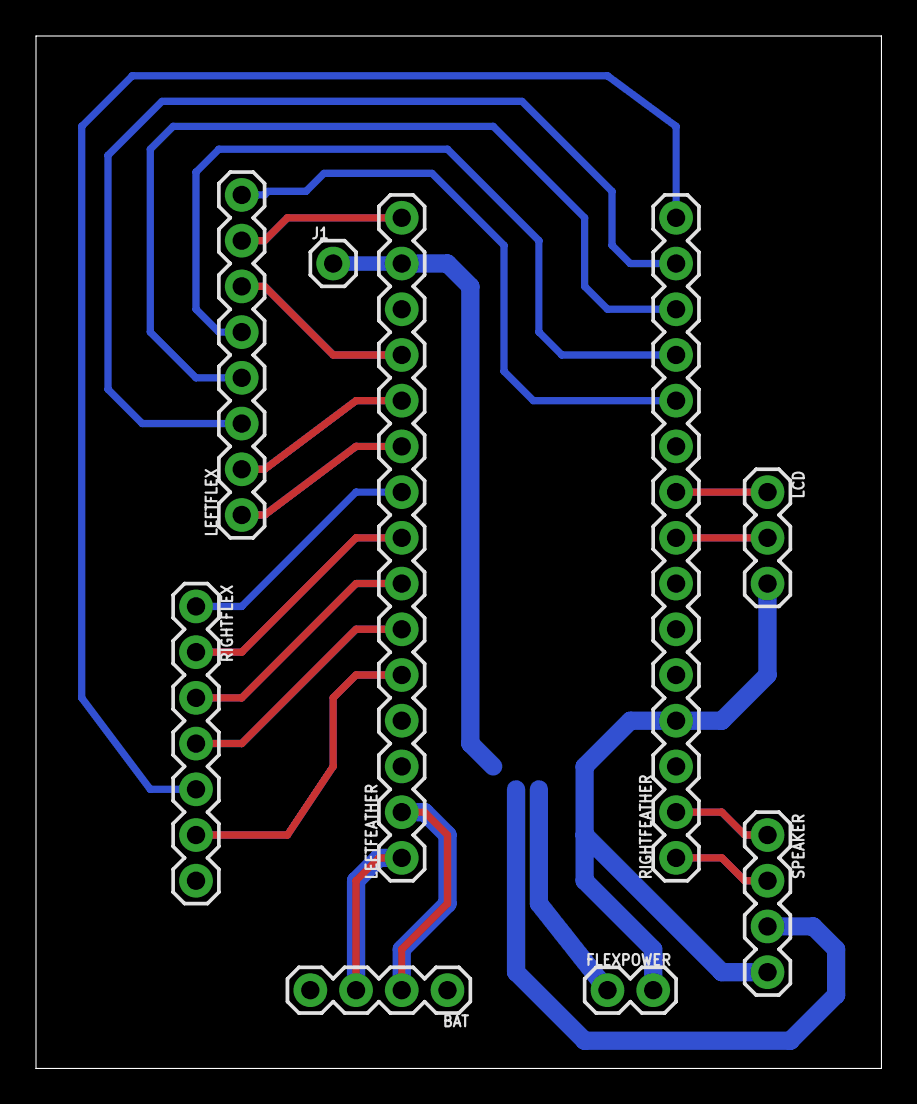
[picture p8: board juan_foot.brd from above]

Board: 2 copper layers, 47.0 x 57.4 mm, 9 parts (0 on the bottom side), 22 nets.

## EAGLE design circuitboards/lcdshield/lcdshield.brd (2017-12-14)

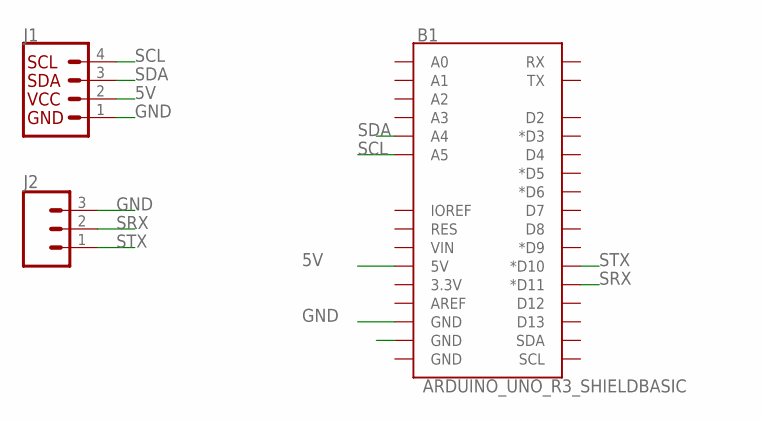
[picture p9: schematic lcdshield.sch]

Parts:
B1: ARDUINO_UNO_R3_SHIELDBASIC; UNO_R3_SHIELD
J1: I2C_STANDARD; 1X04
J2: CONN_03; 1X03

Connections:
5V: B1.5V, J1.2
GND: B1.GND@1 (GND), B1.GND@2 (GND), J1.1, J2.3
SCL: B1.A5, J1.4
SDA: B1.A4, J1.3
SRX: B1.D11 (*D11), J2.2
STX: B1.D10 (*D10), J2.1

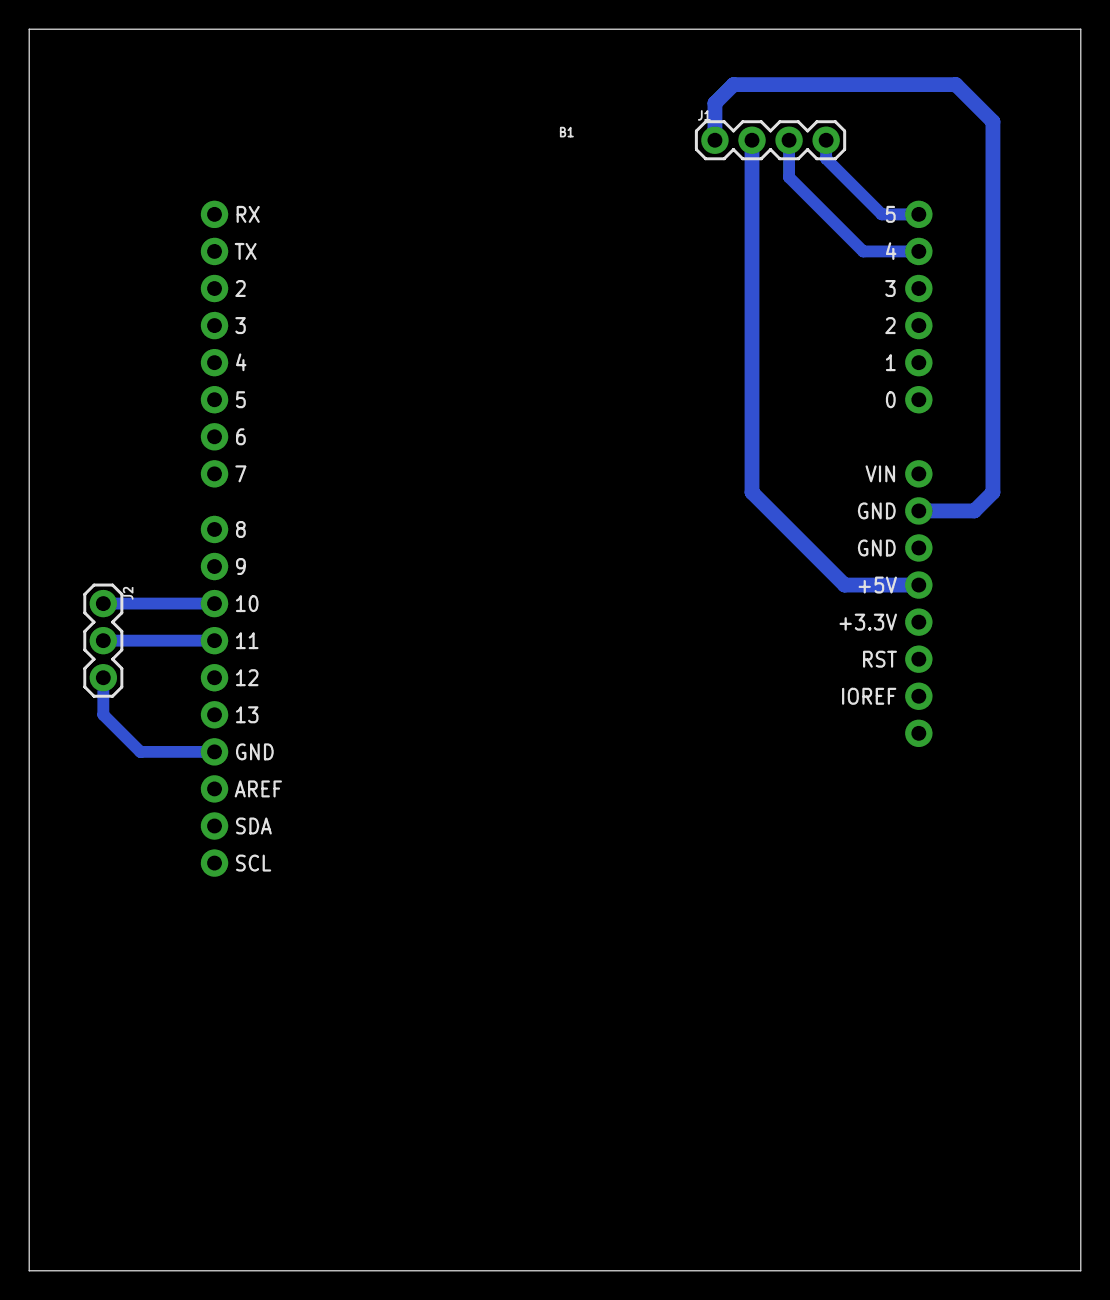
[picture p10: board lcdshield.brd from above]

Board: 2 copper layers, 72.1 x 85.1 mm, 3 parts (0 on the bottom side), 6 nets.

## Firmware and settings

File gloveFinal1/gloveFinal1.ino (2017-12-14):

#include <Wire.h>
#include <SoftwareSerial.h>
#include <stdlib.h>
#include <string.h>
#include <FreeSixIMU.h>
#include <FIMU_ADXL345.h>
#include <FIMU_ITG3200.h>

int angles[3]; // yaw pitch roll
float accel[3];
float alpha = 0.5;

int classify = 0;
char ltr = '\0';
int edit = 0;


/////////////////////
// Glove constants //
/////////////////////

// Set the FreeSixIMU object
FreeSixIMU sixDOF = FreeSixIMU();

//LCD and Speech 
int LCD_RX = 6;
int LCD_TX = 5;

int Speaker_Out = 1;
int Speaker_In = 0;


SoftwareSerial emicSerial(Speaker_Out, Speaker_In); 
SoftwareSerial LCDSerial(6,5);

// Sensor Data
int ring_side = 8;
int middle_tip = 13;
int middle_b = 9;
int middle_side = 10;
int index_tip = 11;
int index_side = 17;
int pinky_side = 12;
const int thumb = A2;
const int index = A1;
const int middle = A0;
const int ring = A6;
const int pinky = A7;


int thumb_value = 0;
int index_value = 0;
int middle_value = 0;
int ring_value = 0;
int pinky_value = 0;


const int thumbBias = 260;
const int thumb_a = 8;

const int indexBias = 200;
const int index_a = 8;

const int middleBias = 200;
const int middle_a = 10.5;

const int ringBias = 200;
const int ring_a = 11.5;

const int pinkyBias = 410;
const int pinky_a = 10;

String lcd_buffer = "|";
int cursor_index = 0;

int speech_flag = 0;

int edit_mode = 0;
String edit_symbol = "!";

////////////////////////////////////
//Feedback variable initialization//
////////////////////////////////////

float data[12];
float prev_data[12];

//////////////////////////////
//Glove State Initialization//
//////////////////////////////
 
typedef enum{
  INITIAL,
  CLASSIFY_MOVING, 
  CLASSIFY,
  CLASSIFY_PRINT,
  CLASSIFY_WAIT,
  EDIT,  
  EDIT_MOVING,
  EDIT_CLASSIFY,
  EDIT_EXECUTE,
  EDIT_WAIT,
  CLASSIFY_I_J,
  CLASSIFY_Z_1,
  CLASSIFY_Z_2,
  CLASSIFY_Z_3
} gloveState;



// LCD

void add_letter()
{
  lcd_buffer = lcd_buffer.substring(0,cursor_index) + ltr + lcd_buffer.substring(cursor_index);
  cursor_index++;
}

void delete_letter()
{
  lcd_buffer = lcd_buffer.substring(0,cursor_index-1) + lcd_buffer.substring(cursor_index);
  cursor_index--;
}


void move_cursor(int direction)
{
  //Direction 0 = left, Direction 1 = right
  String word_swap;
  if (direction)
    {
      if(!(lcd_buffer.length() == cursor_index + 1))
      {
        word_swap = lcd_buffer.substring(cursor_index + 1, cursor_index + 2);
        if (edit_mode)
        {
          lcd_buffer = lcd_buffer.substring(0, cursor_index) + word_swap + edit_symbol + lcd_buffer.substring(cursor_index + 2);  
        }
        else
        {
          lcd_buffer = lcd_buffer.substring(0, cursor_index) + word_swap + "|" + lcd_buffer.substring(cursor_index + 2); 
        }
        
        cursor_index++;
      }
    }
  else
    {     
      if(cursor_index != 0)
      {
        word_swap = lcd_buffer.substring(cursor_index - 1, cursor_index);
        if (edit_mode)
        {
          lcd_buffer = lcd_buffer.substring(0, cursor_index - 1) + edit_symbol + word_swap + lcd_buffer.substring(cursor_index + 1);  
        }
        else
        {
          lcd_buffer = lcd_buffer.substring(0, cursor_index - 1) + "|" + word_swap + lcd_buffer.substring(cursor_index + 1);  
        }
     
        cursor_index--;
      }
    } 
}

void clear_screen()
{
  lcd_buffer = "|";
  cursor_index = 0;
}

void speech()
{
  String speech_string = lcd_buffer.substring(0,cursor_index) + lcd_buffer.substring(cursor_index + 1);
  //  emicSerial.print("N7"); // select voice
  emicSerial.print('S');  // Convert text to speech
  emicSerial.print(speech_string);  
  // Send the desired string to convert to speech
  emicSerial.print('\n');
  // Wait here until the Emic 2 responds with a ":" indicating it's ready to accept the next command
  while (emicSerial.read() != ':');   
  //delay(500);
}

void send_to_lcd()
{
    LCDSerial.write(ltr);
}


/////////////////////
//Feedback Function//
/////////////////////

void update_data(void)
{
  for(int i = 0; i < 15; i++)
  {
    prev_data[i] = data[i];
  }
}

////////////////////////////////////
//Flex sensor Calibration Function//
////////////////////////////////////

float getVoltage(int pin)
{
  // This function has one input parameter, the analog pin number
  // to read. You might notice that this function does not have
  // "void" in front of it; this is because it returns a floating-
  // point value, which is the true voltage on that pin (0 to 5V).

  // Here's the return statement for this function. We're doing
  // all the math we need to do within this statement:
  return (analogRead(pin));
 
}

void calibrate(void)
{
  update_data();

  thumb_value = (getVoltage(thumb) - thumbBias)/thumb_a;
  index_value = (getVoltage(index) - indexBias)/index_a;
  middle_value = (getVoltage(middle) - middleBias)/middle_a;
  ring_value = (getVoltage(ring) - ringBias)/ring_a;
  pinky_value = (getVoltage(pinky) - pinkyBias)/pinky_a;

  
/* *Note* getAngles function should not be in calibration but in classify state since state transition depends only on flex movement */
  sixDOF.getRawValues(angles);

 accel[0] = (float)(angles[0]) / 245;
 accel[1] = (float)(angles[1]) / 245;
 accel[2] = (float)(angles[2]) / 245;
  
  accel[0] = (1 - alpha)*data[12] + alpha * accel[0];
  accel[1] = (1 - alpha)*data[13] + alpha * accel[1];
  accel[2] = (1 - alpha)*data[14] + alpha * accel[2];

// Feedback array *Note* Not sure if this should have its own function; might be helpful
  data[0] = digitalRead(ring_side);
  data[1] = digitalRead(middle_tip);
  data[2] = digitalRead(middle_b);
  data[3] = digitalRead(middle_side);
  data[4] = digitalRead(index_tip);
  data[5] = digitalRead(index_side);
  data[6] = digitalRead(pinky_side);
  data[7] = thumb_value;
  data[8] = index_value;
  data[9] = middle_value;
  data[10] = ring_value;
  data[11] = pinky_value;
  data[12] = accel[0];
  data[13] = accel[1];
  data[14] = accel[2];

  
}



int array_equal(void)
{
  if((data[0] == prev_data[0])
  && (data[1] == prev_data[1])
  && (data[2] == prev_data[2])
  && (data[3] == prev_data[3])
  && (data[4] == prev_data[4])
  && (data[5] == prev_data[5])
  && (data[6] == prev_data[6])
  && (data[7] >= prev_data[7] - 2 && data[7] <= prev_data[7] + 2)
  && (data[8] >= prev_data[8] - 2 && data[8] <= prev_data[8] + 2)
  && (data[9] >= prev_data[9] - 2 && data[9] <= prev_data[9] + 2) 
  && (data[10] >= prev_data[10] - 2 && data[10] <= prev_data[10] + 2)
  && (data[11] >= prev_data[11] - 2 && data[11] <= prev_data[11] + 2))
  {
    return 1;
  }
  else
  {
    return 0;
  }
}


int check_movement(void)
{
  if (array_equal() == 1)
  {
    return 1;
  }
  else
  {
    return 0;
  }
}

bool check_range(int i1, int i2, int i3, int i4,int i5, int i6, int i7, int i8,int i9, int i10, int i11, int i12,
int i13, int i14, int i15, int i16,int i17, int i18, int i19, int i20,int i21, int i22, int i23, int i24)
{
int bounds[24] = { i1,  i2,  i3,  i4, i5,  i6,  i7,  i8, i9,  i10,  i11,  i12,
 i13,  i14,  i15,  i16, i17, i18, i19, i20, i21,  i22,  i23,  i24};
  bool return_val = true;
  int bounds_i = 0;
  for(int i = 0; i < 12; i++)
  {
    if(!(bounds[bounds_i] <= data[i] && data[i] <= bounds[bounds_i+1]))
    {
      return_val = false;
    }
    bounds_i += 2;
  }
  return return_val;
}



bool check_range(int i1, int i2, int i3, int i4,int i5, int i6, int i7, int i8,int i9, int i10, int i11, int i12,
int i13, int i14, int i15, int i16,int i17, int i18, int i19, int i20,int i21, int i22, int i23, int i24, float i25,
float i26, float i27, float i28, float i29, float i30)
{
int bounds[24] = { i1,  i2,  i3,  i4, i5,  i6,  i7,  i8, i9,  i10,  i11,  i12,
 i13,  i14,  i15,  i16, i17, i18, i19, i20, i21,  i22,  i23,  i24};
  bool return_val = true;
  int bounds_i = 0;
  for(int i = 0; i < 12; i++)
  {
    if(!(bounds[bounds_i] <= data[i] && data[i] <= bounds[bounds_i+1]))
    {
      return_val = false;
    }
    bounds_i += 2;
  }


  if( 
     !(( (i25)  <= data[12] && data[12] <= i26)
  && ( (i27)  <= data[13] && data[13] <= i28)
  && ( (i29)  <= data[14] && data[14] <= i30)))
  {
    return_val = false;
  }

  return return_val;
}


void edit_classifier()
{
if (check_range(0,0,0,0,0,0,0,0,0,0,0,0,0,0, 11,18,0,3,0,3,14,19,12,16))
  {
    ltr = '2';
    edit = 1;   
    clear_screen();
    //move_cursor(0)
    //move_cursor(1)
    //delete_letter()    
  } else if (check_range(0,0,0,0,0,0,0,0,0,0,0,0,0,0, 11,20,0,5,0,5,0,5,12,19))
  {
    ltr = '3';
    edit = 1;
    //move_cursor(0);
    //clear_screen()
    move_cursor(0);
    //move_cursor(1)
    //delete_letter()
  } else if (check_range(0,0,0,0,0,0,0,0,0,0,0,0,0,0, 11,18,0,4,15,25,15,25,15,25))
  {
    ltr = '1';
    edit = 1;   
    //move_cursor(1);
    //clear_screen()
    //move_cursor(0)
    //move_cursor(1)
    delete_letter();
  }else if (check_range(0,0,0,0,0,0,0,0,0,0,0,0,0,0, 15,25,0,7,0,7,0,7,0,7))
  {
    ltr = '4';
    edit = 1;   
    //move_cursor(1);
    //clear_screen()
    //move_cursor(0)
    move_cursor(1);
    //delete_letter()    
  } else if (check_range(0,0,0,0,0,0,0,0,0,0,0,0,0,0, 0,8,0,5,0,5,12,18,0,5))
  {
    ltr = '?';
    edit = 2;  
    send_to_lcd(); 
    edit_mode = 0;
  }
  else
  {
//   Serial.println("Edit CLassifier FAILED to match Gesture");
   ltr = '-';
   edit = 0;
  }
  //classify = 1;
  
}



void classifier()
{

   // A
  if(  check_range(0,0,0,0,0,0,0,0,0,0,1,1,0,0,10,19,15,25,15,25,15,25,13,25))
  {
    ltr = 'A';
    classify = 1;   
  } else if (check_range(0,0,0,0,0,1,0,0,0,0,0,0,0,0,15,25,0,7,0,7,0,7,0,7))
  {
    ltr = 'B';
    classify = 1;   
  } else if (check_range(0,0,0,0,0,1,0,0,0,0,0,0,0,0,9,16,15,18,13,18,13,18,7,13))
  {
    ltr = 'C';
    classify = 1;   
  } else if (check_range(0,0,1,1,0,0,0,0,0,0,0,0,0,0, 7,18,0,7,10,15,10,16,7,15))
  {
    ltr = 'D';
    classify = 1;   
  } else if (check_range(0,0,0,0,0,0,0,0,0,0,0,0,0,0, 21,25,16,25,16,25,16,25,16,25))
  {
    ltr = 'E';
    classify = 1;   
  
  } else if (check_range(0,0,0,0,0,0,0,1,1,1,0,0,0,0, 11,18,15,20,0,7,0,7,0,7))
  {
    ltr = 'F';
    classify = 1;   
  } else if (check_range(0,0,0,0,0,1,0,0,0,0,0,0,0,0, 4,10,6,13,15,25,15,25,15,25, 0,0.20,0.9,1.2,(-0.20),(0.45)))
  {
    ltr = 'G';
    classify = 1;   
  } else if (check_range(1,1,0,0,1,1,0,0,0,0,0,0,0,0, 10,18,0,5,0,5,10,20,10,20, 0.20,0.30,0.90,1.10,(-0.30),(-0.20)))
  {
    ltr = 'H';
    classify = 1;   
  
  } else if (check_range(0,0,0,0,0,1,0,1,0,0,1,1,0,0, 16,22,13,25,13,25,13,25,0,5))
  {
    ltr = 'I';
    classify = 1;   
  } else if (check_range(0,0,0,0,0,1,1,1,1,1,0,0,0,0, 7,18,0,6,3,10,12,22,12,22, 0.9,1.1,0.25,0.4,0.20,0.5))
  {
    ltr = 'K';
    classify = 1;   
  } else if (check_range(0,0,0,0,0,1,0,0,0,0,0,0,0,0, 0,6,0,4,15,25,15,25,15,25))
  {
    ltr = 'L';
    classify = 1;   
  
  } else if (check_range(0,0,0,0,0,1,0,1,0,0,0,0,1,1, 12,23,13,25,13,25,13,22,13,20))
  {
    ltr = 'M';
    classify = 1;   
  } else if (check_range(1,1,0,0,0,1,0,0,0,0,0,0,0,0, 13,23,13,25,13,25,13,22,13,20))
  {
    ltr = 'N';
    classify = 1;   
  } else if (check_range(0,0,1,1,0,1,0,0,0,0,0,0,0,0, 11,20,12,20,13,18,13,18,7,20))
  {
    ltr = 'O';
    classify = 1;   
  } else if (check_range(0,0,0,0,0,1,1,1,1,1,0,0,0,0, 7,18,0,6,3,10,12,22,12,22, 0.1,0.3,0.4,0.5,0.8,0.95))
  {
    ltr = 'P';
    classify = 1;    
  } else if (check_range(0,0,0,0,0,1,0,0,0,0,0,0,0,0, 4,10,6,13,15,25,15,25,15,25, (-0.30),0.15,0.20,0.45,0.85,1))
  {
    ltr = 'Q';
    classify = 1;   
  }
  else if (check_range(0,0,0,0,0,0,0,0,0,0,0,0,0,0, 12,20,0,3,0,7,15,20,13,16))
  {
    ltr = 'R';
    classify = 1;   
  } else if (check_range(0,0,0,0,1,1,0,0,0,0,0,0,0,0, 17,22,19,28,15,28,15,25,15,20))
  {
    ltr = 'S';
    classify = 1;   
  } else if (check_range(0,0,0,0,0,1,1,1,1,1,0,0,0,0, 12,23,13,25,13,25,13,22,13,20))
  {
    ltr = 'T';
    classify = 1;   
  } else if (check_range(1,1,0,0,1,1,0,1,0,0,0,0,0,0, 11,18,0,3,0,3,14,22,10,16, 0.90,1.10,0.10,0.20,0.30,0.40))
  {
    ltr = 'U';
    classify = 1;   
  } else if (check_range(1,1,0,0,0,0,0,0,0,0,0,0,0,0, 11,18,0,5,0,5,14,22,10,16))
  {
    ltr = 'V';
    classify = 1;   
  } else if (check_range(0,0,0,0,0,0,0,0,0,0,0,0,0,0, 11,20,0,5,0,5,0,5,12,19))
  {
    ltr = 'W';
    classify = 1;   
  } else if (check_range(0,0,0,0,0,1,0,0,0,0,0,0,0,0, 11,20,12,20,16,22,17,22,15,22))
  {
    ltr = 'X';
    classify = 1;   
  } else if (check_range(0,0,0,0,0,1,0,0,0,0,0,0,0,0, 0,11,17,23,17,20,17,20,0,11))
  {
    ltr = 'Y';
    classify = 1;   
  } else if (check_range(0,0,0,0,0,1,0,0,0,0,0,0,0,0, 11,17,0,5,18,22,18,22,17,20))
  {
    ltr = 'Z';
    classify = 1;   
  } else if (check_range(0,0,0,0,0,0,0,0,0,0,0,0,0,0, 0,8,8,19,0,5,0,5,0,5))
  {
    ltr = ' '; //// Spaceeeeeee
    classify = 1;   
  } else if (check_range(0,0,0,0,0,0,0,0,0,0,0,0,0,0, 0,8,0,8,8,22,0,5,0,5))
  {
    ltr = '+'; ///// Speeeeeeeeech
    classify = 1;   
    speech_flag = 1;
  } else if (check_range(0,0,0,0,0,0,0,0,0,0,0,0,0,0, 0,8,0,8,0,8,12,20,0,8))
  {
    ltr = '!'; ///// Enter ediiiiiiit
    classify = 2; 
    edit = 0;
    edit_mode = 1;
    send_to_lcd();
  }
  else
  {
   //Serial.println("\0");
   ltr = '-';
   classify = 0;
  }
  //classify = 1;
  
}

int acceleration_checker()
{
  // Checks the acceleration values for J

  if( 
     ( 0.40 <= data[12] && data[12] <= 0.60)
  && ( (-0.25)  <= data[13] && data[13] <= 0.0)
  && ( (-1.05)  <= data[14] && data[14] <= -0.80))
  {
    return 1;
  }
  else
  {
    return 0;
  }

}

int horizontal_negative()
{
  if (data[13] < -0.45)
  {
    return 1;
  }
  else
  {
    return 0;
  }
}
int horizontal_positive()
{
  if ((data[13] > 0.45) && (data[14] > 1.2))
  {
    return 1;
  }
  else
  {
    return 0;
  }
}

void setup()
{
  //GPIO pin initialization
  pinMode(ring_side, INPUT);
  pinMode(middle_tip, INPUT);
  pinMode(middle_b, INPUT);
  pinMode(middle_side, INPUT);
  pinMode(index_tip, INPUT);
  pinMode(index_side, INPUT);
  pinMode(pinky_side, INPUT);
  pinMode(Speaker_Out, INPUT);
  pinMode(Speaker_In, OUTPUT);
  
  //Serial USB setup
  LCDSerial.begin(9600);
  emicSerial.begin(9600);
  //  Serial.begin(9600);

  // Speaker board set_up
  emicSerial.print('\n');             // Send a CR in case the system is already up
  while (emicSerial.read() != ':');   // When the Emic 2 has initialized and is ready, it will send a single ':' character, so wait here until we receive it
  delay(10);                          // Short delay
  emicSerial.flush();                 // Flush the receive buffer
  
  //I2C pins setup
  Wire.begin();
  
  //Accelerometer and Gyroscope Setup
  delay(5);
  sixDOF.init(); //begin the IMU
  delay(5); 
}

void loop()
{

  //Code to check if check movement function and feedback works
  
  static gloveState state = INITIAL;
  //static int edit = 0;

 if(state == INITIAL && check_movement()){
    state = INITIAL;
  }
   
 if(state == INITIAL && !check_movement()){
    state = CLASSIFY_MOVING;
  }

  else if(state == CLASSIFY_MOVING && check_movement()){
    state = CLASSIFY;
  }
  
  else if(state == CLASSIFY_MOVING && !check_movement()){
    state = CLASSIFY_MOVING;
  }
  
  else if(state == CLASSIFY && classify == 1 && check_movement()){
    state = CLASSIFY_PRINT;
  }
  
  else if(state == CLASSIFY && classify == 0 && check_movement()){
    state = CLASSIFY_MOVING;
  }
  
  else if(state == CLASSIFY && classify == 1 && !check_movement()){
    state = CLASSIFY_PRINT;
  }
  
  else if(state == CLASSIFY && classify == 0 && !check_movement()){
    state = CLASSIFY_MOVING;
  }

  else if(state == CLASSIFY && classify == 2 && check_movement()){
//    Serial.println("");  
//    Serial.println("EDIT MODE ENTERED");  
//    Serial.println(" ");  
    state = EDIT_WAIT;
  }

  else if(state == CLASSIFY && classify == 2 && !check_movement()){
//    Serial.println("");  
//    Serial.println("EDIT MODE ENTERED");  
//    Serial.println(" ");  
    state = EDIT_WAIT;
  }
  
  else if(state == CLASSIFY_PRINT){
    state = CLASSIFY_WAIT;
  }
  
  else if(state == CLASSIFY_WAIT && check_movement()){
    state = CLASSIFY_WAIT;
  }
  
  else if(state == CLASSIFY_WAIT && !check_movement()){
    state = CLASSIFY_MOVING;
  }

  else if(state == EDIT && check_movement()){
    state = EDIT_MOVING;
  }

  else if(state == EDIT && !check_movement()){
    state = EDIT_MOVING;
  }

  else if(state == EDIT_MOVING && check_movement()){
    state = EDIT_CLASSIFY;
  }

  else if(state == EDIT_CLASSIFY && edit == 1 ){
    state = EDIT_EXECUTE;
  }
  
  else if(state == EDIT_CLASSIFY && edit == 0 && check_movement()){
    state = EDIT_MOVING;
  }

  else if(state == EDIT_CLASSIFY && edit == 2){
    classify = 0;
    edit = 0;
    state = CLASSIFY_WAIT;
  }
  
  else if(state == EDIT_MOVING && !check_movement()){
    state = EDIT_MOVING;
  }  

  else if(state == EDIT_EXECUTE && edit == 3){
    state = EDIT_WAIT;
  }  

  else if(state == EDIT_WAIT && check_movement()){
    state = EDIT_WAIT;
  }

  else if(state == EDIT_WAIT && !check_movement()){
    state = EDIT_MOVING;
  }
  else if(state == CLASSIFY && ltr == 'I')         /// I/J State Machine 
  {
    state = CLASSIFY_I_J;
  }
  else if(state == CLASSIFY_I_J && !check_movement())
  {
    ltr = 'I';
    state = CLASSIFY_PRINT;
  }
  else if(state == CLASSIFY_I_J && !acceleration_checker())
  {
    state = CLASSIFY_I_J;
  }
  else if(state == CLASSIFY_I_J && acceleration_checker())
  {
    ltr = 'J';
    state = CLASSIFY_PRINT;
  }
  else if(state == CLASSIFY && ltr == 'Z')      /// Z State Machine
  {
    state = CLASSIFY_Z_1;
  }
  else if(state == CLASSIFY_Z_1 && !check_movement())
  {
    state = CLASSIFY_MOVING;
  }
  else if(state == CLASSIFY_Z_1 && horizontal_negative())
  {
    state = CLASSIFY_Z_2;
  }
  else if(state == CLASSIFY_Z_2 && horizontal_positive())
  {
    state = CLASSIFY_Z_3;
  }
  else if(state == CLASSIFY_Z_2 && !check_movement())
  {
    state = CLASSIFY_MOVING;
  }
  else if(state == CLASSIFY_Z_3 && horizontal_negative())
  {
    state = CLASSIFY_PRINT;
  }
  else if(state == CLASSIFY_Z_3 && !check_movement())
  {
    state = CLASSIFY_MOVING;
  }



  switch (state){
    case INITIAL:

      calibrate();
      break;


    case CLASSIFY_MOVING:
//      Serial.print("ring: ");
//      Serial.print(data[0]);
//      Serial.print("  m_tip: ");
//      Serial.print(data[1]);
//      Serial.print("  m_b: ");
//      Serial.print(data[2]);
//      Serial.print("  m_side: ");
//      Serial.print(data[3]);
//      Serial.print("  i_tip: ");
//      Serial.print(data[4]);
//      Serial.print("  i_side: ");
//      Serial.print(data[5]);
//      Serial.print("  p_side: ");
//      Serial.println(data[6]);
//      Serial.print("  thumb: ");
//      Serial.print(data[7]);
//      Serial.print("  index: ");
//      Serial.print(data[8]);
//      Serial.print("  midd: ");
//      Serial.print(data[9]);
//      Serial.print("  ring: ");
//      Serial.print(data[10]);
//      Serial.print("  pink: ");
//      Serial.println(data[11]);  
        

      calibrate();    
      break;

    case CLASSIFY_WAIT:
      classify = 0;
      calibrate();
      break;
            
    case EDIT_CLASSIFY: 
      edit_classifier();
      //Serial.println("EDIT_CLASSIFY ");
      calibrate();   
      break; 
    case CLASSIFY:
      classifier();
      calibrate();
      break;

    case CLASSIFY_PRINT:
      if (speech_flag == 1)
      {
        send_to_lcd();
        //delay(250);
        speech();
        speech_flag = 0; 
      }
      else
      {
        add_letter();
        send_to_lcd();
      }
      
//      Serial.println(lcd_buffer);
      // Sends the string buffer to the lcd to print
      break;

    case EDIT:
    //Serial.println("EDIT ");
      edit_classifier();
      calibrate();
      break;
    case EDIT_MOVING:
    //Serial.println("EDIT_MOVING ");
      calibrate();
      break;
  
    case EDIT_EXECUTE:
//      Serial.println();
//      Serial.print("EDIT_EXECUTE   ");
//      Serial.print(ltr);
//      Serial.println();
      send_to_lcd();
      
      edit = 3;  
      break;
    case EDIT_WAIT:
      edit = 0;
      calibrate();
      //Serial.println(" ");
      //Serial.print("edit wait: ");
      //Serial.println(" ");
      break;

    case CLASSIFY_I_J:
      calibrate();
      break;

    case CLASSIFY_Z_1:
      break;

    case CLASSIFY_Z_2:
      break;

    case CLASSIFY_Z_3:
      break;


    default:
      calibrate();
      break;
  }
  // To send data from the Arduino to the serial monitor window,
  // we use the Serial.print() function.
  // Note that the above statement uses "println", which will insert
  // a "carriage return" character at the end of whatever it prints,
  // moving down to the NEXT line.
  delay(250); // repeat once per second (change as you wish!)
}

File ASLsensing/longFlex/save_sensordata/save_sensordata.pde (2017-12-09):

import processing.serial.*;

Serial myPort;  // Create object from Serial class
String val;     // Data received from the serial po
PrintWriter output;

void setup()
{
 // String portName = Serial.list()[4]; 
  //change the 0 to a 1 or 2 etc. to match your port
  myPort = new Serial(this, "COM17", 9600); 
  output = createWriter("testOscarLetterZ.txt");
}
     
void draw()
{
  if ( myPort.available() > 0) 
  {  // If data is available,  
  String val = myPort.readStringUntil('\n'); 
  if (val != null)
  {
    output.print(val);
    println(val);
  // read it and store it in val
  }  
  }
}

void keyPressed() {
    output.flush();  // Writes the remaining data to the file
    output.close();  // Finishes the file
    exit();  // Stops the program
}

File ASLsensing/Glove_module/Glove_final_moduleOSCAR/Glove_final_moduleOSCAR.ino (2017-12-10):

/* Code functional description goes here
 *  
 *  
 *  
 */



#include <Wire.h>

#include <FreeSixIMU.h>
#include <FIMU_ADXL345.h>
#include <FIMU_ITG3200.h>

float angles[3]; // yaw pitch roll

////////////////////////////
// Glove global constants //
////////////////////////////

int LCD_TX = 5;
int LCD_RX = 6;
int Speaker_In = 0;
int Speaker_Out = 1; 

int ms = 250; //250 ms: current delay

// Set the FreeSixIMU object
FreeSixIMU sixDOF = FreeSixIMU();

char ltr = 'A';
// Sensor Data
int ring_side = 8;
int middle_tip = 13;
int middle_b = 9;
int middle_side = 10;
int index_tip = 11;
int index_side = 17;
int pinky_side = 12;
const int thumb = A2;
const int index = A1;
const int middle = A0;
const int ring = A6;
const int pinky = A7;
// Sensor Data


int thumb_value = 0;
int index_value = 0;
int middle_value = 0;
int ring_value = 0;
int pinky_value = 0;
float thumb_flex_voltage;
float index_flex_voltage;
float middle_flex_voltage;
float ring_flex_voltage;
float pinky_flex_voltage;

//Filter
int filter_ring_side = 0;
int filter_middle_tip = 0;
int filter_middle_b = 0;
int filter_middle_side = 0;
int filter_index_tip = 0;
int filter_index_side = 0;
int filter_pinky_side = 0;
int filter_thumb_flex = 0;
int filter_index_flex = 0;
int filter_middle_flex = 0;
int filter_ring_flex = 0;
int filter_pinky_flex = 0;

const int thumbBias = 260;
const int thumb_a = 8;

const int indexBias = 200;
const int index_a = 8;

const int middleBias = 200;
const int middle_a = 10.5;

const int ringBias = 200;
const int ring_a = 11.5;

const int pinkyBias = 410;
const int pinky_a = 10;

////////////////////////////////////
//Feedback variable initialization//
////////////////////////////////////

float data[12];
float prev_data[12];

//////////////////////////////
//Glove State Initialization//
//////////////////////////////
 
typedef enum{
  INITIAL,
  CLASSIFY_MOVING, 
  CLASSIFY,
  CLASSIFY_PRINT,
  CLASSIFY_WAIT,
  EDIT,  
  EDIT_MOVING,
  EDIT_CLASSIFY,
  EDIT_EXECUTE,
  EDIT_WAIT
  
} gloveState;

/////////////////////
//Feedback Function//
/////////////////////

void update_data(void)
{
prev_data[0] = data[0];
prev_data[1] = data[1];
prev_data[2] = data[2];
prev_data[3] = data[3];
prev_data[4] = data[4];
prev_data[5] = data[5];
prev_data[6] = data[6];
prev_data[7] = data[7];
prev_data[8] = data[8];
prev_data[9] = data[9];
prev_data[10] = data[10];
prev_data[11] = data[11];

}

void filter_data(void)
{
filter_ring_side += data[0];
filter_middle_tip += data[1];
filter_middle_b += data[2];
filter_middle_side += data[3];
filter_index_tip += data[4];
filter_index_side = data[5];
filter_pinky_side = data[6];
filter_thumb_flex = data[7];
filter_index_flex = data[8];
filter_middle_flex = data[9];
filter_ring_flex = data[10];
filter_pinky_flex = data[11];

}

////////////////////////////////////
//Flex sensor Calibration Function//
////////////////////////////////////

void calibrate(void)
{
  update_data();

  thumb_flex_voltage = getVoltage(thumb);
  index_flex_voltage = getVoltage(index);
  middle_flex_voltage = getVoltage(middle);
  ring_flex_voltage = getVoltage(ring);
  pinky_flex_voltage = getVoltage(pinky);

  thumb_value = (thumb_flex_voltage - thumbBias)/thumb_a;
  index_value = (index_flex_voltage - indexBias)/index_a;
  middle_value = (middle_flex_voltage - middleBias)/middle_a;
  ring_value = (ring_flex_voltage - ringBias)/ring_a;
  pinky_value = (pinky_flex_voltage - pinkyBias)/pinky_a;

  
/* *Note* getAngles function should not be in calibration but in classify state since state transition depends only on flex movement */
  sixDOF.getAngles(angles);


// Feedback array *Note* Not sure if this should have its own function; might be helpful
  data[0] = digitalRead(ring_side);
  data[1] = digitalRead(middle_tip);
  data[2] = digitalRead(middle_b);
  data[3] = digitalRead(middle_side);
  data[4] = digitalRead(index_tip);
  data[5] = digitalRead(index_side);
  data[6] = digitalRead(pinky_side);
  data[7] = thumb_value;
  data[8] = index_value;
  data[9] = middle_value;
  data[10] = ring_value;
  data[11] = pinky_value;


}
////////////////////////
// Feedback functions //
////////////////////////

int array_equal(void)
{
  if(data[0] == prev_data[0]
  && data[1] == prev_data[1]
  && data[2] == prev_data[2]
  && data[3] == prev_data[3]
  && data[4] == prev_data[4]
  && data[5] == prev_data[5]
  && data[6] == prev_data[6]
  && data[7] == prev_data[7]
  && data[8] == prev_data[8]
  && data[9] == prev_data[9] 
  && data[10] == prev_data[10]
  && data[11] == prev_data[11])
  {
    return 1;
  }
  else
  {
    return 0;
  }
}

/*
int check_movement(void)
{
  if (array_equal() == 1)
  {
    return 1;
  }
  else
  {
    return 0;
  }
}
*/

int check_movement()
{
  char* randomletter;
   if (ltr == classifier(randomletter))
  {
    return 1;
  }
  else
  {
    return 0;
  } 
}

/////////////////////////////////////////////////////////////////
// ASL Classifier function & possibly Edit Classifier function //
/////////////////////////////////////////////////////////////////

/* Example of Check:
   // Letter
  if(
     # <= data[0] <= #  // ring_side 
  && # <= data[1] <= #  // middle_tip
  && # <= data[2] <= #  // middle_b
  && # <= data[3] <= #  // middle_side 
  && # <= data[4] <= #  // index_tip
  && # <= data[5] <= #  // index_side
  && # <= data[6] <= #  // pinky_side
  && # <= data[7] <= #  // thumb
  && # <= data[8] <= #  // index
  && # <= data[9] <= #  // middle
  && # <= data[10] <= # // ring
  && # <= data[11] <= # // pinky
  )
  {
    ltr = 'Letter';
    classify = 1;
    //return;
   
  }
*/

char classifier(char *ltr)
{
  static int classify = 0; 


   // A
  if(
     0 <= data[0] <= 0  // ring_side 
  && 0 <= data[1] <= 0  // middle_tip
  && 0 <= data[2] <= 0  // middle_b
  && 0 <= data[3] <= 0  // middle_side 
  && 0 <= data[4] <= 0  // index_tip
  && 1 <= data[5] <= 1  // index_side
  && 0 <= data[6] <= 0  // pinky_side
  && 5 <= data[7] <= 12  // thumb
  && 16 <= data[8] <= 22  // index
  && 16 <= data[9] <= 21  // middle
  && 16 <= data[10] <= 22 // ring
  && 15 <= data[11] <= 20 // pinky
  )
  {
    ltr = 'A';
    classify = 1;
    return ltr;
   
  }

  // H
 
  if(
     1 <= data[0] <= 1  // ring_side 
  && 0 <= data[1] <= 0  // middle_tip
  && 0 <= data[2] <= 0  // middle_b
  && 0 <= data[3] <= 0  // middle_side 
  && 0 <= data[4] <= 0  // index_tip
  && 0 <= data[5] <= 0  // index_side
  && 0 <= data[6] <= 0  // pinky_side
  && 12 <= data[7] <= 14  // thumb
  && 0 <= data[8] <= 1  // index
  && 0 <= data[9] <= 4  // middle
  && 16 <= data[10] <= 18 // ring
  && 14 <= data[11] <= 16 // pinky
  )
  {
    ltr = 'H';
    classify = 1;
    return ltr;
   
  }
 
  else
  {
   ltr = '\0';
   classify = 1;
   return ltr;
  }
  classify =1;
  
}

/*Edit function classifer goes here

*/

///////////////////////
// ADC read function //
///////////////////////
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

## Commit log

2017-11-10 Code for pause at letter and both touch sensors
2017-11-14 added calibration on glove 2.0
2017-11-20 Add Desicion tree test implementation in Python
    [gesture_test.csv, gesture_train.csv]
2017-11-23 added code for textToSpeech board
2017-11-28 Added Accel/Gyro code in accel/accel.ino
2017-12-02 pcb testing
2017-12-03 feather pcb locoooos
    [juan_foot.brd, juan_foot.sch]
2017-12-03 pcb for nano almost ready
    [juan_foot.brd, juan_foot.sch]
2017-12-03 Added Ground Plane
2017-12-04 pcb updated with new connections. Added 3V plane
    [juan_foot.brd, juan_foot.sch]
2017-12-06 finished glove pcb and speaker pcb
    [juan_foot.brd, juan_foot.sch, speakerboard.brd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]
2017-12-09 Add Edit Function Datasets and Add PCB Test Base Code
2017-12-09 final pcb
    [juan_foot.brd, juan_foot.sch]
2017-12-09 verified outputs from PCB work. errthing work w/o computerrr
    [lcdshield.brd, lcdshield.sch]
2017-12-12 LCD serial
    [unoshield.fzz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]
2017-12-13 working code is: ...battery_speech
    [unoshield.fzz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]
2017-12-13 calibrated values for aashyk, a-z (without accel) and enter edit mode, but without changes to edit functions
2017-12-14 ginal version
    [juan_foot.brd, juan_foot.sch, lcdshield.brd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]

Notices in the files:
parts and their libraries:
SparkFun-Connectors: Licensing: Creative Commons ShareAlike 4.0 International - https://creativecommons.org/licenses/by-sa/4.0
